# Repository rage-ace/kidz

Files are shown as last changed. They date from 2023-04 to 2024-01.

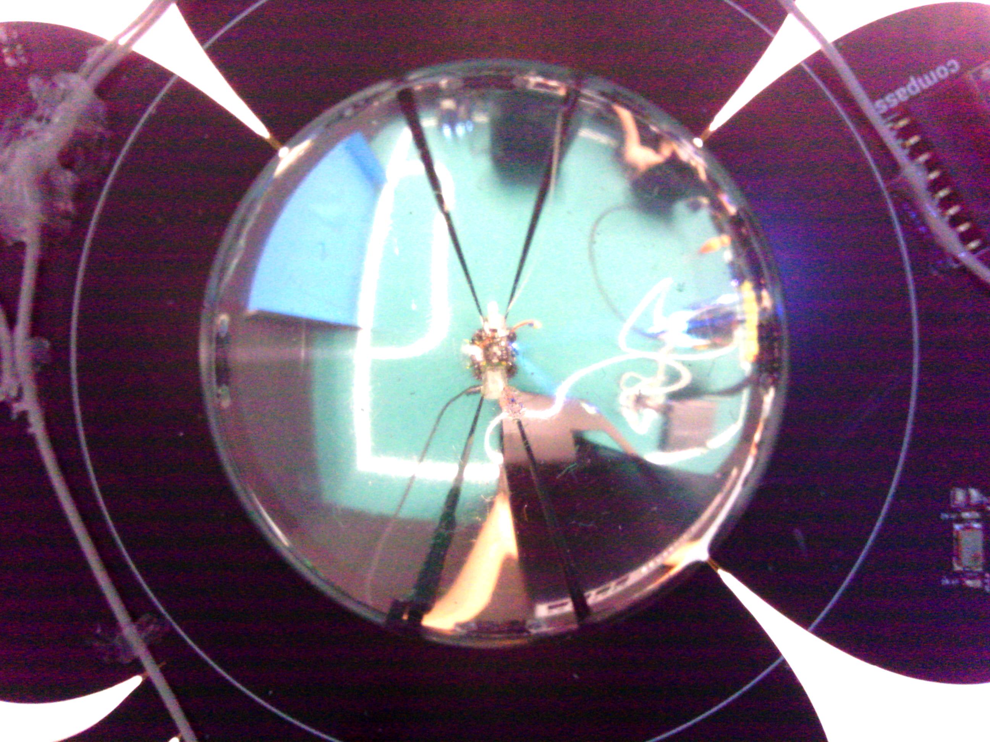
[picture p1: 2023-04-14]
software/coral/snaps/img0002.jpg

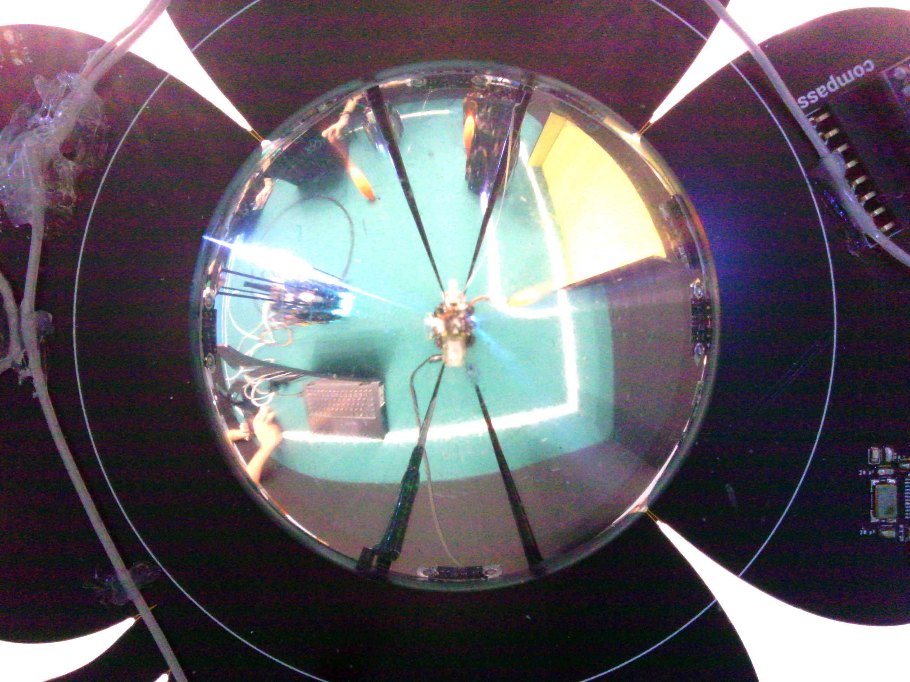
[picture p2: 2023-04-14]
software/coral/snaps/img0001.jpg

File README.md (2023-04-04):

# kidz

Find out more at [notes.skytect.one/robocup](https://notes.skytect.one/robocup)!

```bash
.
├── designs/               # All CAD designs are located here
│   └── pcb-schematics/        # PCB schematics
│       ├── layer1/                # Layer 1 PCB
│       ├── layer2/                # Layer 2 PCB
│       ├── layer3/                # Layer 3 PCB
│       └── layer4/                # Layer 4 PCB
├── software/              # All code is located here
│   ├── coral/             # Code for the Coral Dev Board Mini
│   │   └── ...
│   └── microcontrollers/  # Code for the Teensy 4.0 and STM32F103CBT6s
│       ├── include/           # Shared header files
│       ├── lib/               # Shared libraries
│       ├── src/
│       │   ├── stm32_mux/         # Code for the Layer 1 STM32
│       │   │   ├── include/           # Header files
│       │   │   ├── lib/               # Libraries
│       │   │   ├── main.cpp           # Source code
│       │   │   └── ...
│       │   ├── stm32_imu/         # Code for the Layer 4 IMU STM32
│       │   │   ├── include/           # Header files
│       │   │   ├── lib/               # Libraries
│       │   │   ├── main.cpp           # Source code
│       │   │   └── ...
│       │   ├── stm32_tof/        # Code for the Layer 4 TOF STM32
│       │   │   ├── include/           # Header files
│       │   │   ├── lib/               # Libraries
│       │   │   ├── main.cpp           # Source code
│       │   │   └── ...
│       │   ├── teensy/            # Code for the Layer 3 Teensy
│       │   │   ├── include/           # Header files
│       │   │   ├── lib/               # Libraries
│       │   │   ├── main.cpp           # Source code
│       │   │   └── ...
│       │   └── ...            # Shared source code
│       ├── platform.ini       # PlatformIO configuration file
│       └── ...
├── .gitignore
├── LICENSE
└── README.md
```

## Coral

[Click Me!](software/coral)

## Microcontrollers

### Execution

```bash
cd software/microcontrollers
# Upload and run to Teensy
pio run -e teensy -t upload -t monitor
# Upload to Layer 1 STM32
pio run -e stm32_mux -t upload
```

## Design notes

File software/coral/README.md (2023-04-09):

# Camera 📸

## Setup

```bash
 # Connect to a network to SSH over, and set hostname to "kidz.local"
sudo nmtui
sudo nano /etc/hosts  # Also change your hostname here to "kidz"

# Setup autofocus
snapshot  # Send 'r' to focus once
# The run scripts disable autofocus

# Install python dependencies
sudo python3 -m pip install -r requirements.txt  # We will be running the script with root

# Set up service
sudo apt install -y screen
sudo cp camera.service /etc/systemd/system/
sudo systemctl enable camera  # TODO: THIS DOES NOT WORK (https://stackoverflow.com/questions/75961521/pyserial-write-raises-errno-5-input-output-error-a-while-after-startup-when)
```

## Execution

```bash
# Run the version with a webserver debugger
# Access it at http://kidz.local:8080
sudo sh run_server.sh

# Run the headless version
sudo sh run_noserver.sh
```

## Development

```bash
# Install dependenceis
sudo apt install -y python3-dev
python3 -m pip install --user black pipreqs
echo 'export PATH="/home/mendel/.local/bin:$PATH"' >> ~/.bashrc

pipreqs . --force  # Capture python dependencies to requirements.txt
black .  # Reformat all code
```

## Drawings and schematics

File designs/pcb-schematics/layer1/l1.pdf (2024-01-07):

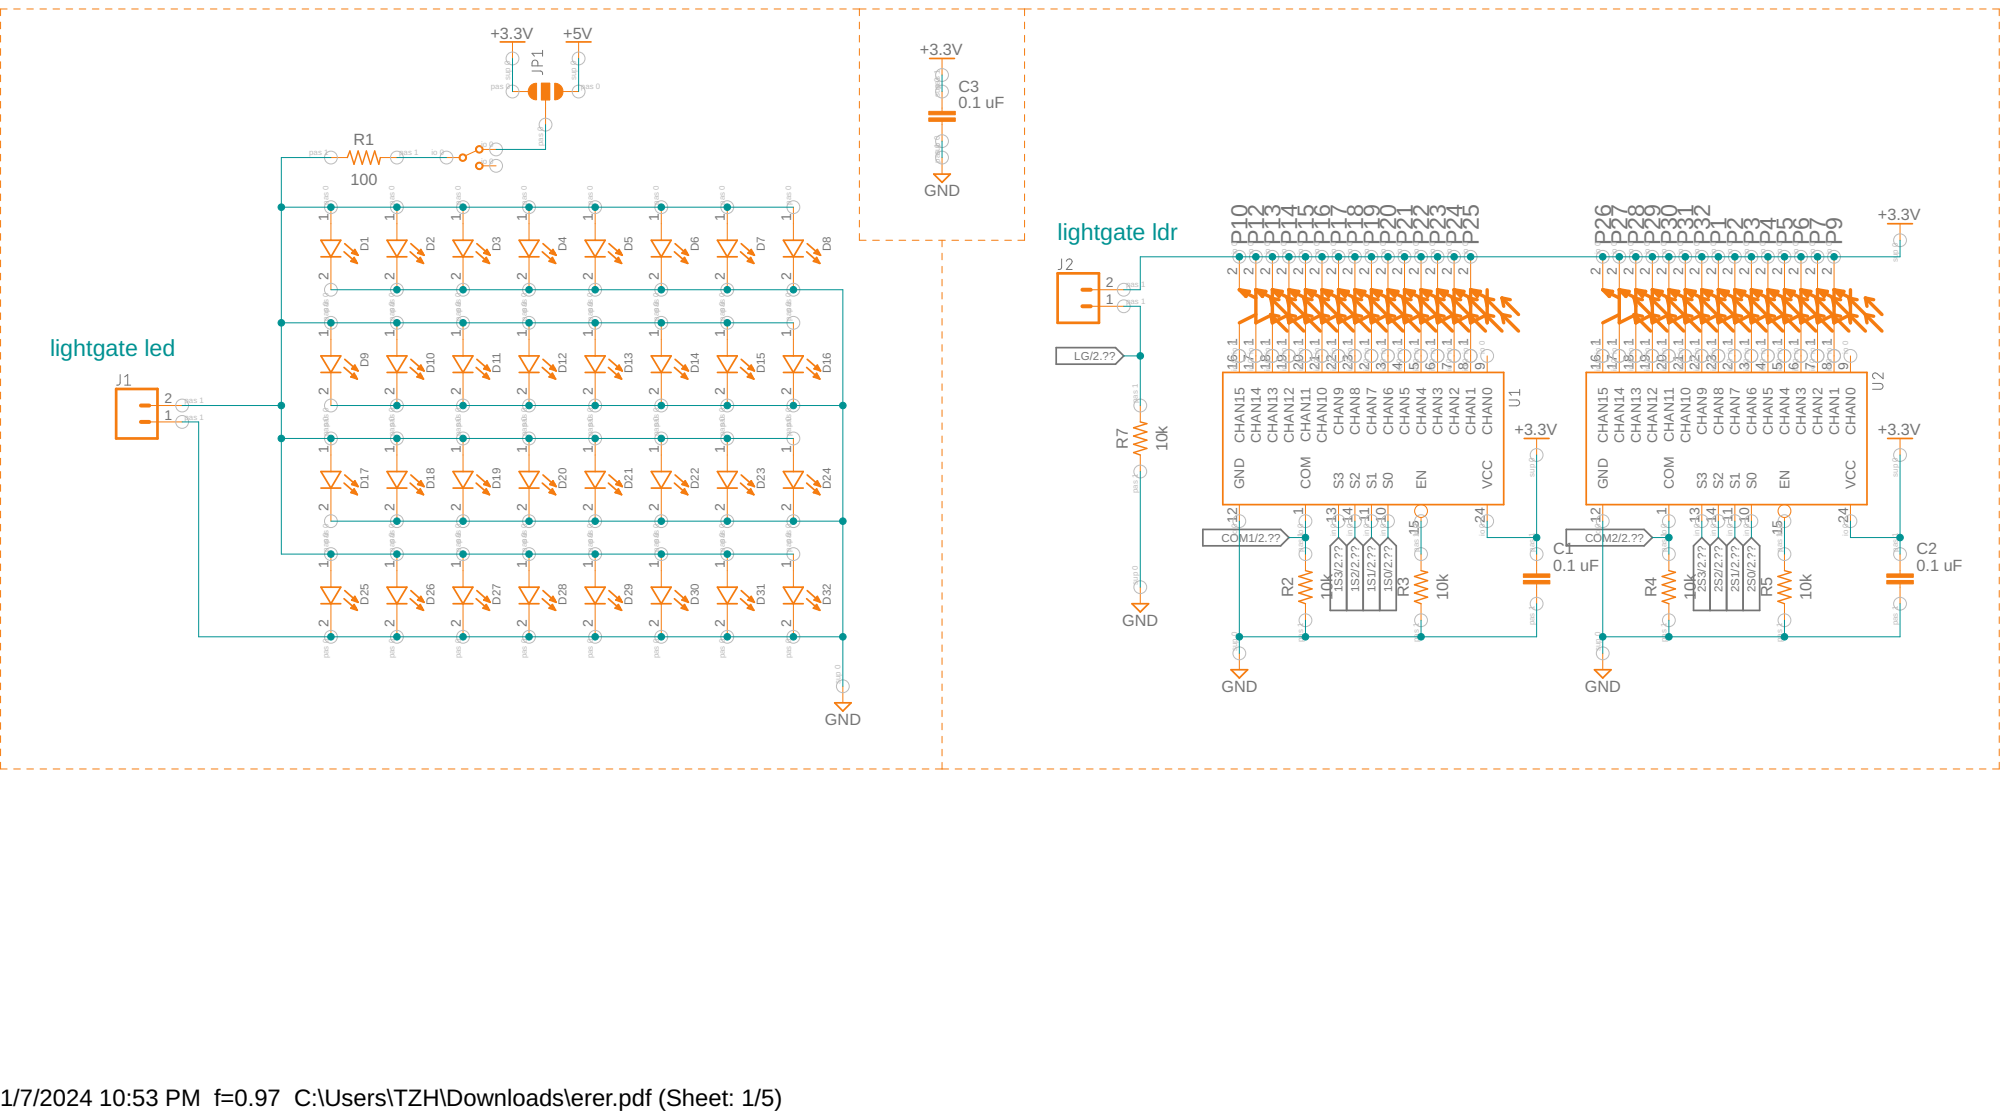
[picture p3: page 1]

1/7/2024 10:53 PM f=0.97 C:\Users\TZH\Downloads\erer.pdf (Sheet: 1/5)

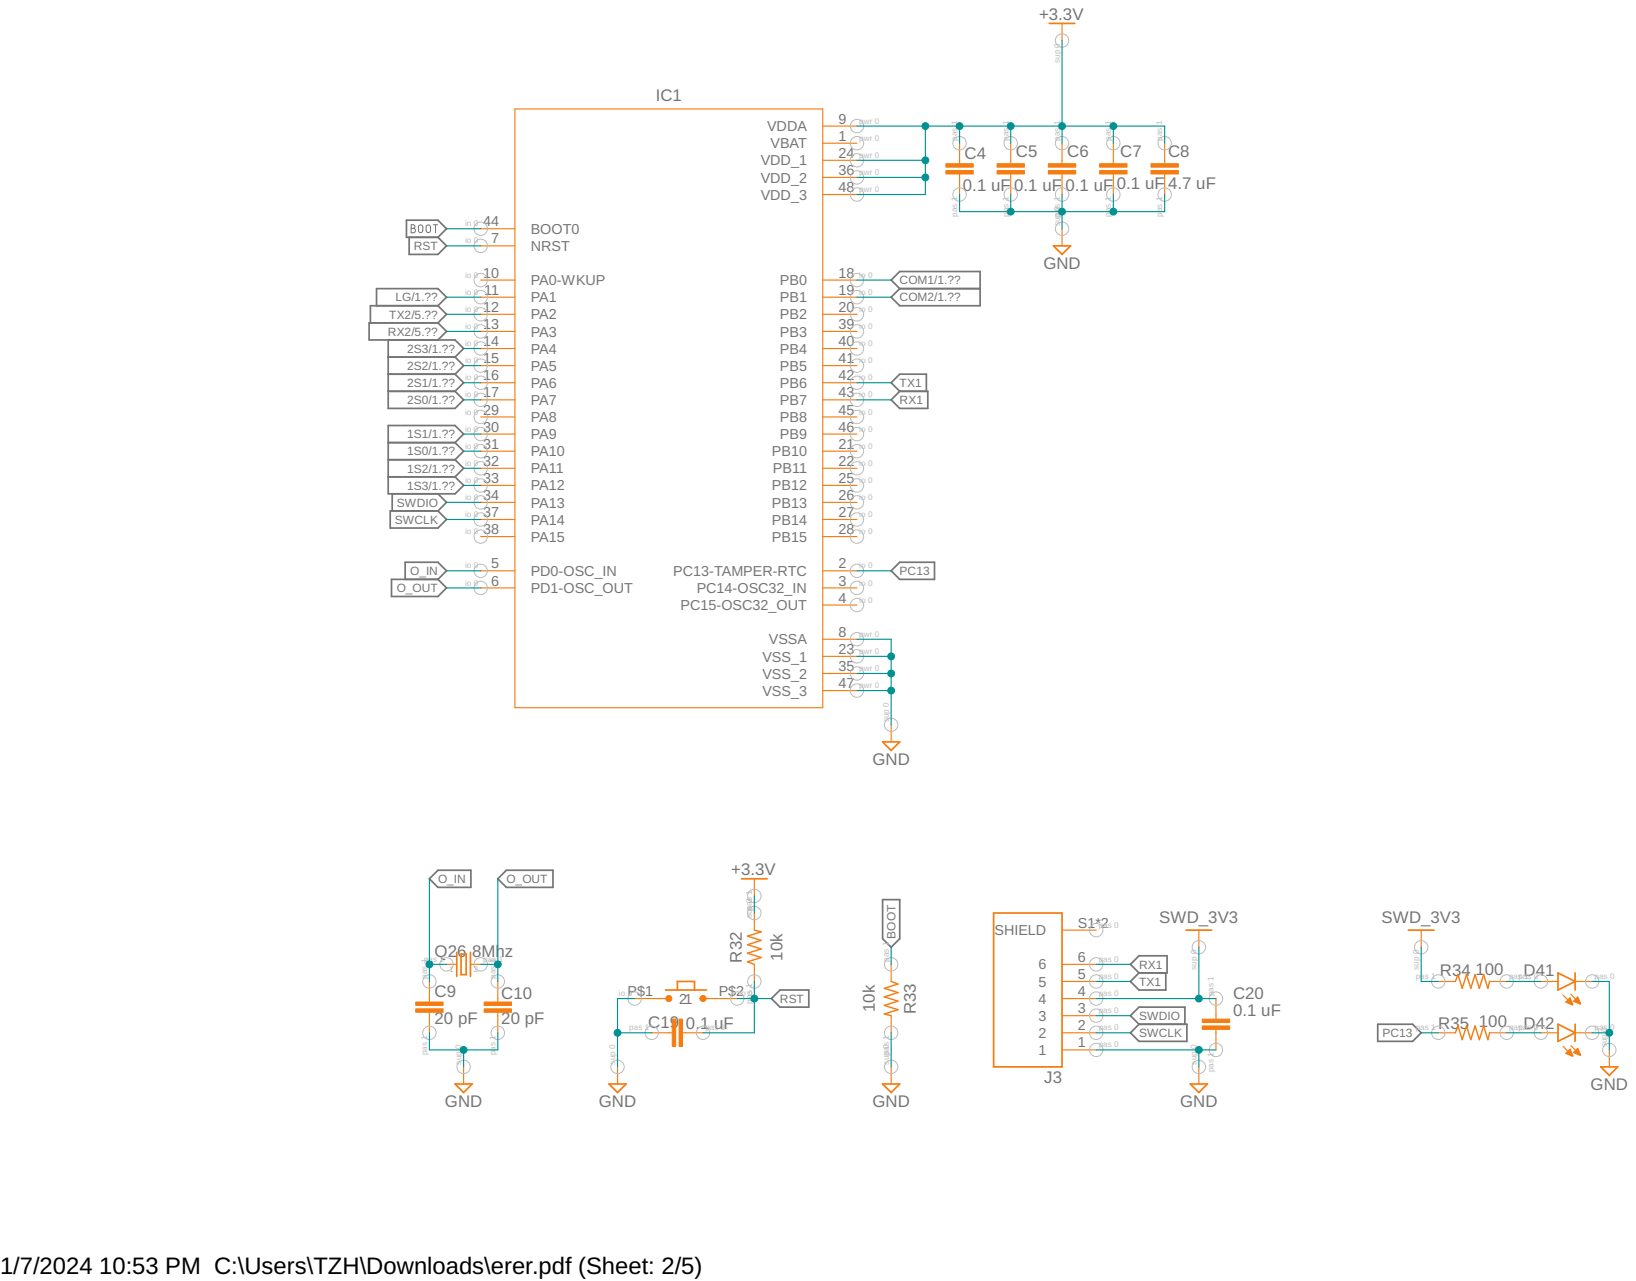
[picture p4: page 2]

1/7/2024 10:53 PM C:\Users\TZH\Downloads\erer.pdf (Sheet: 2/5)

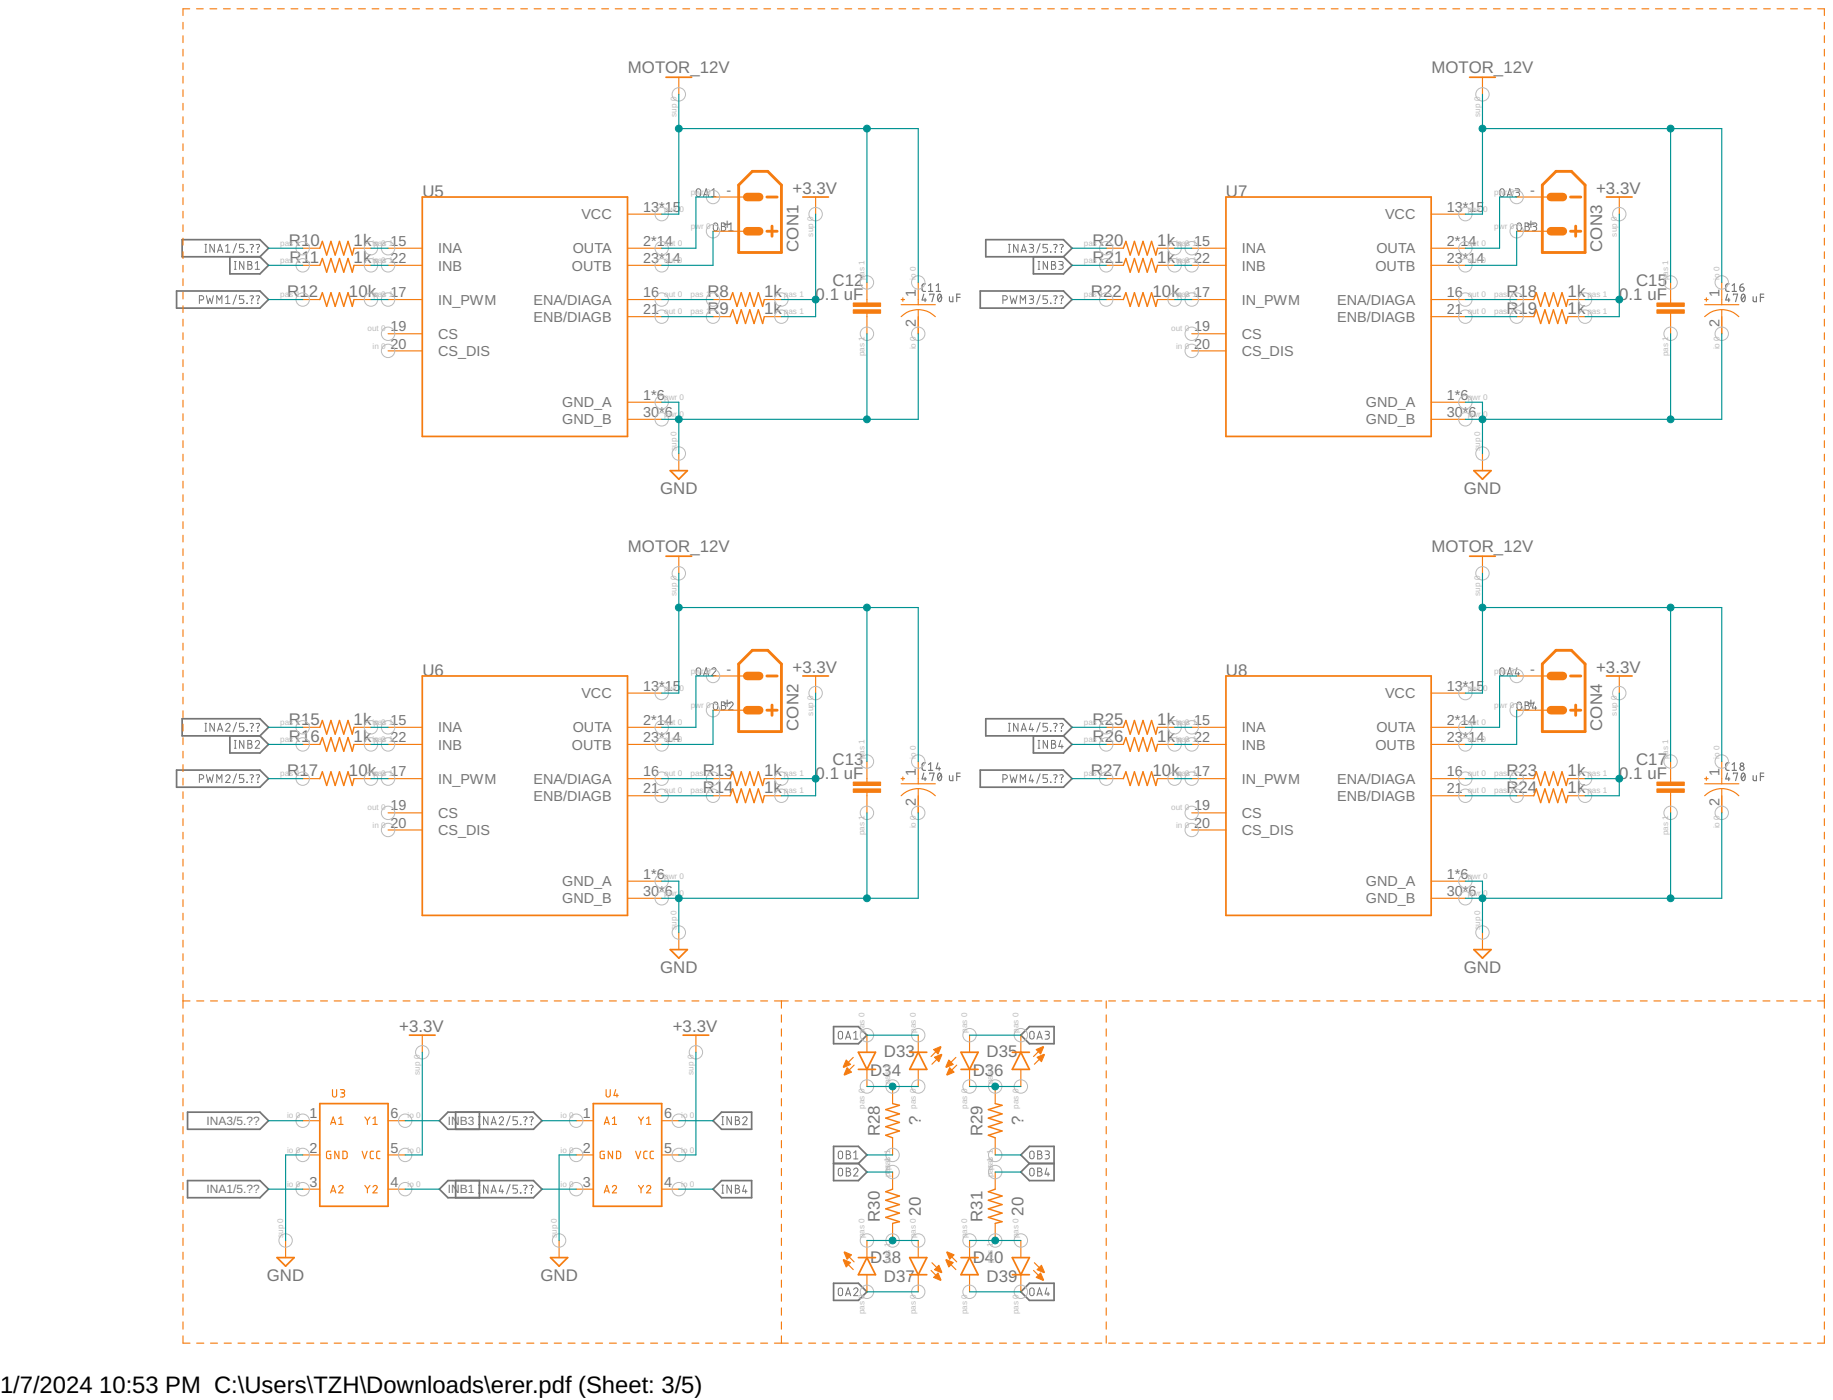
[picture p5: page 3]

1/7/2024 10:53 PM C:\Users\TZH\Downloads\erer.pdf (Sheet: 3/5)

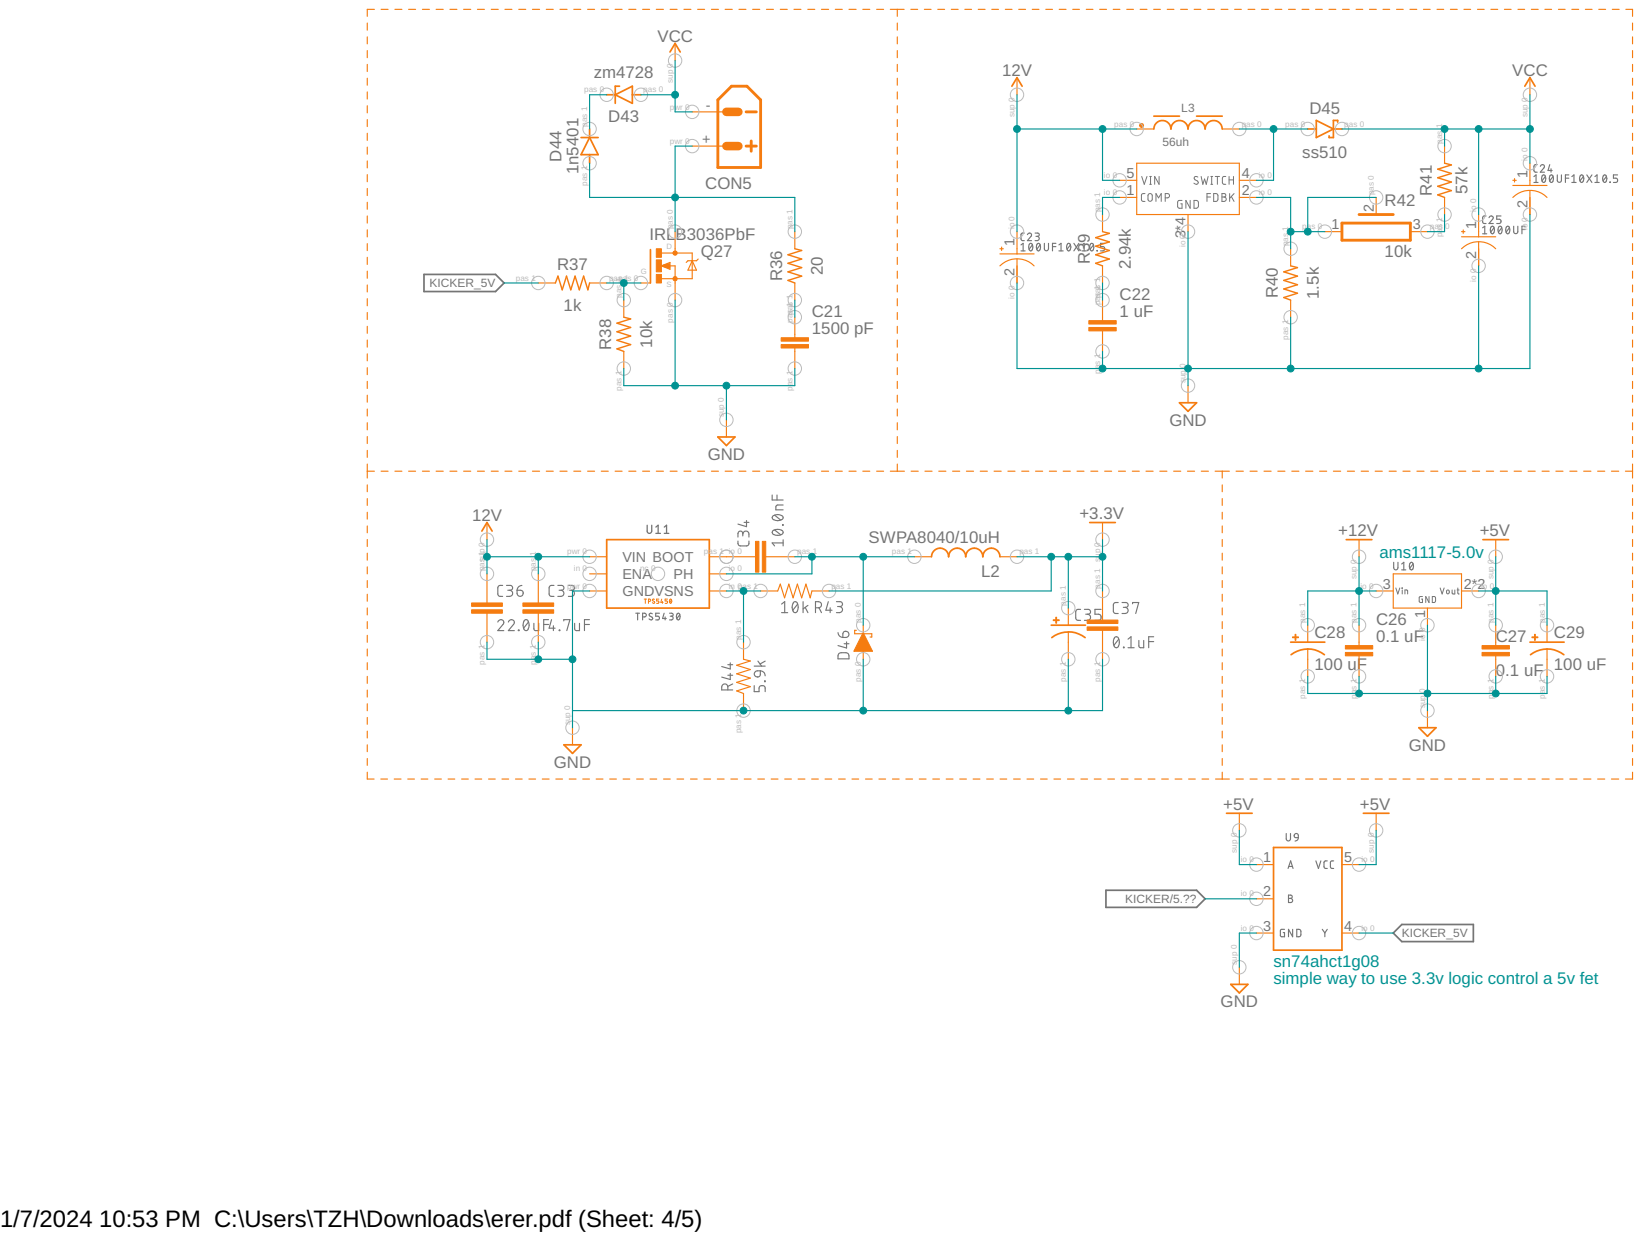
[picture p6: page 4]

pas 1 pas 1

sup 0
sn74ahct1g08
simple way to use 3.3v logic control a 5v fet

1/7/2024 10:53 PM C:\Users\TZH\Downloads\erer.pdf (Sheet: 4/5)

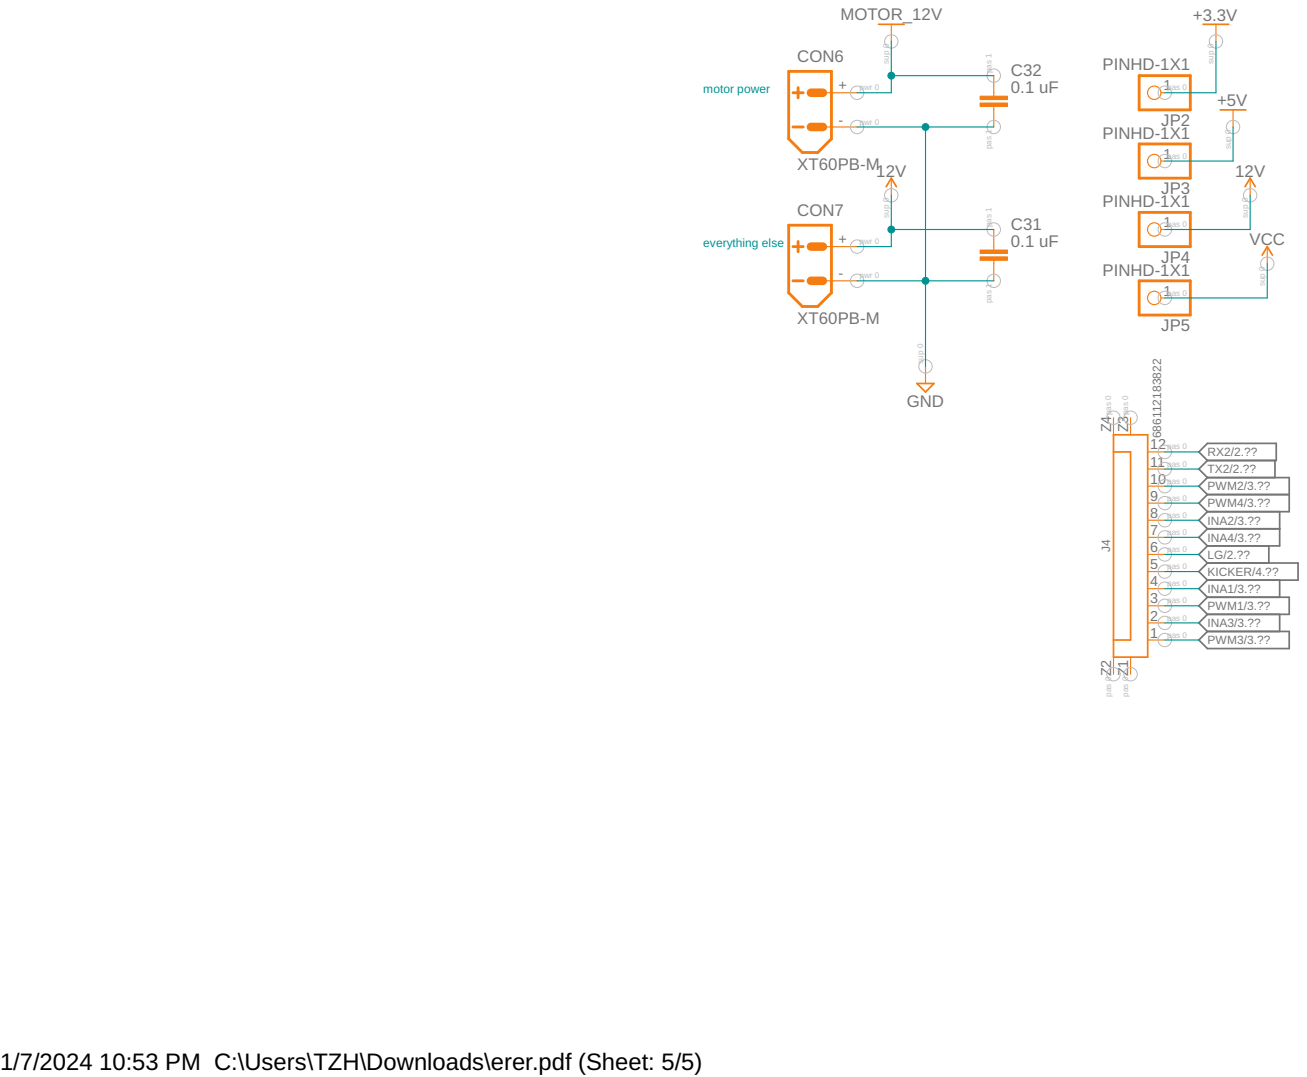
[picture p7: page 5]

1/7/2024 10:53 PM C:\Users\TZH\Downloads\erer.pdf (Sheet: 5/5)

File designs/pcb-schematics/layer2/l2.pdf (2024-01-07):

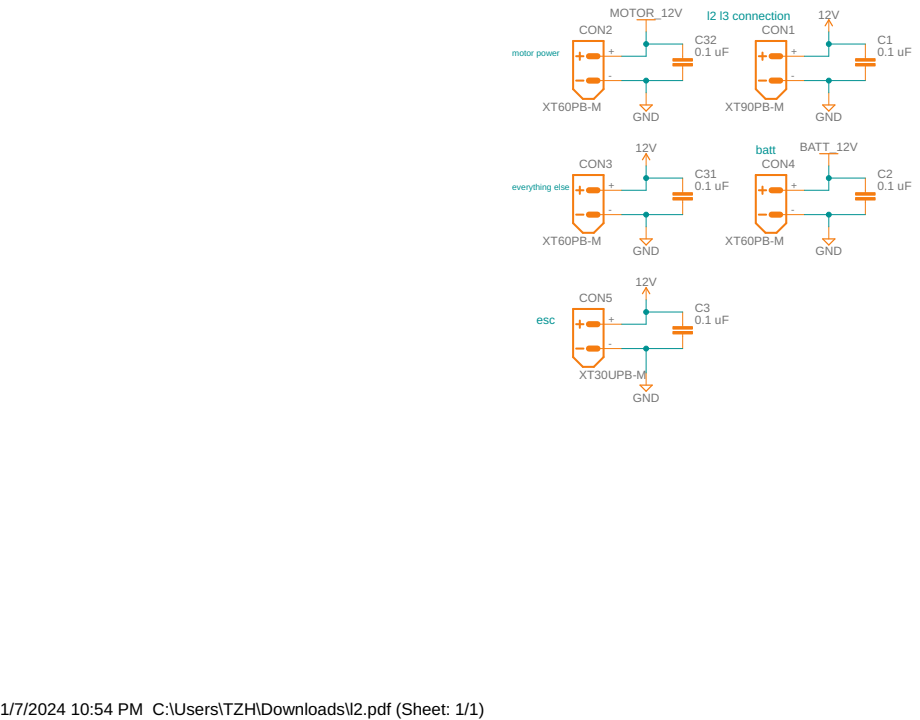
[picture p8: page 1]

1/7/2024 10:54 PM C:\Users\TZH\Downloads\l2.pdf (Sheet: 1/1)

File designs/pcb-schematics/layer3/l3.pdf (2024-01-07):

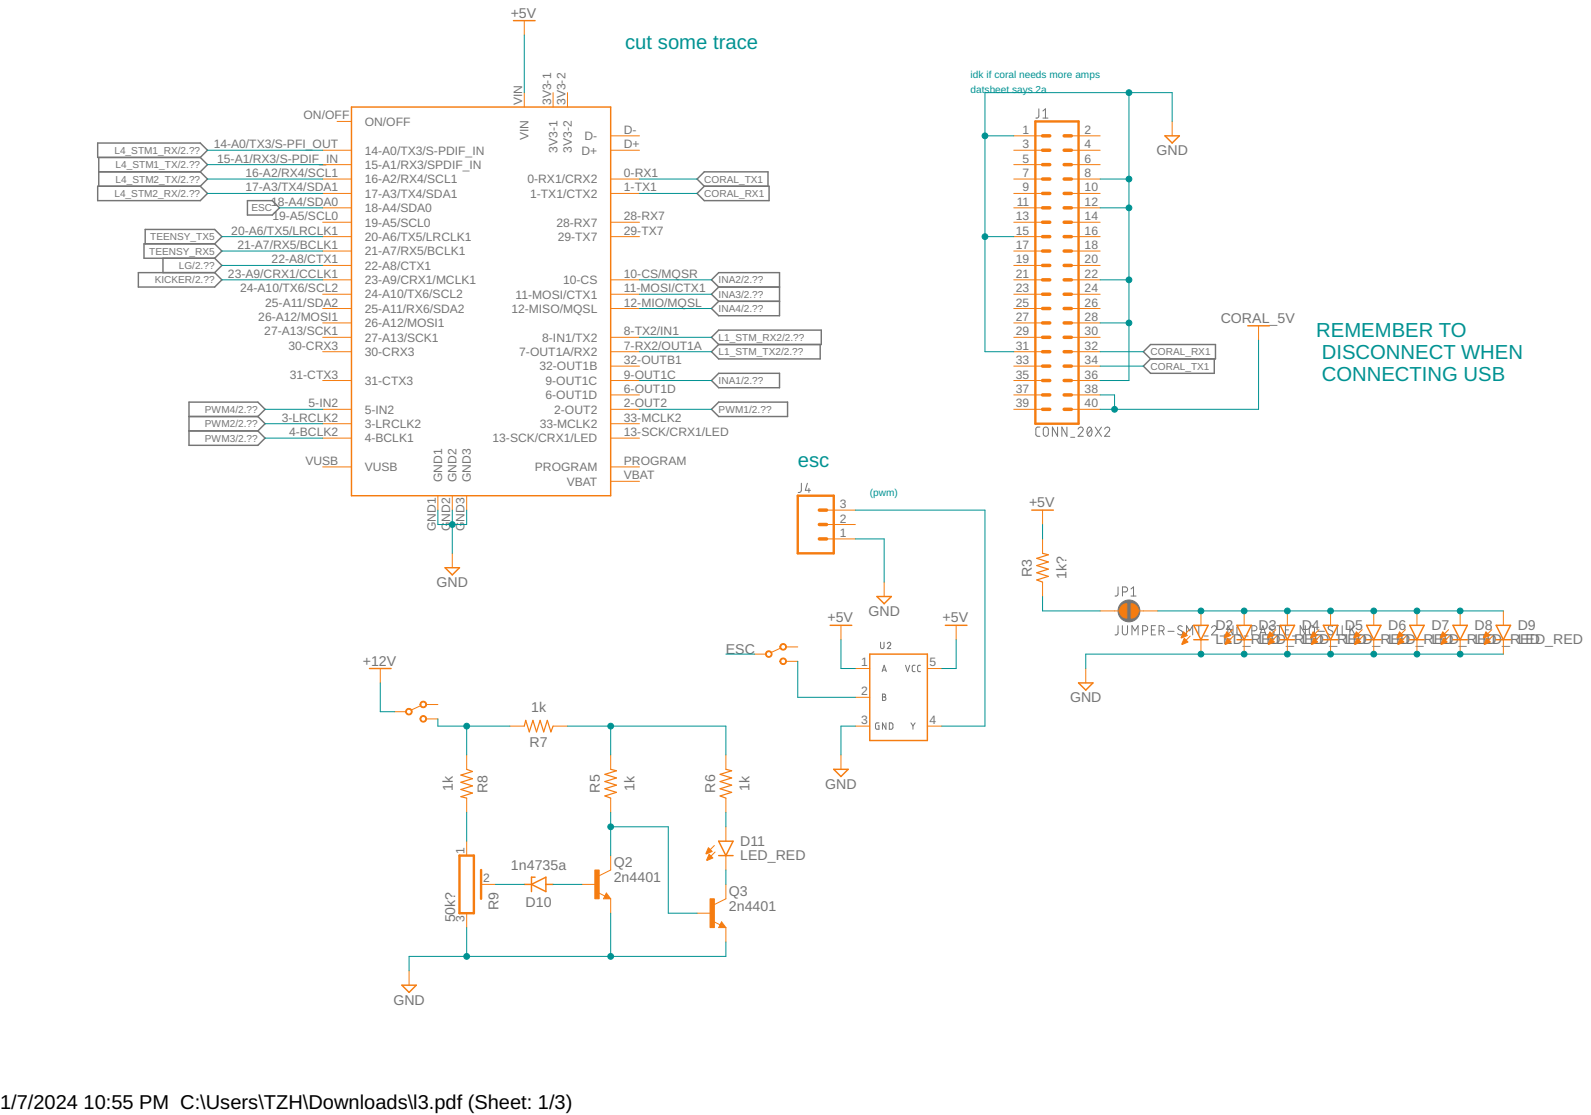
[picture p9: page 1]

idk if coral needs more amps datsheet says 2a

ON/OFF

1/7/2024 10:55 PM C:\Users\TZH\Downloads\l3.pdf (Sheet: 1/3)

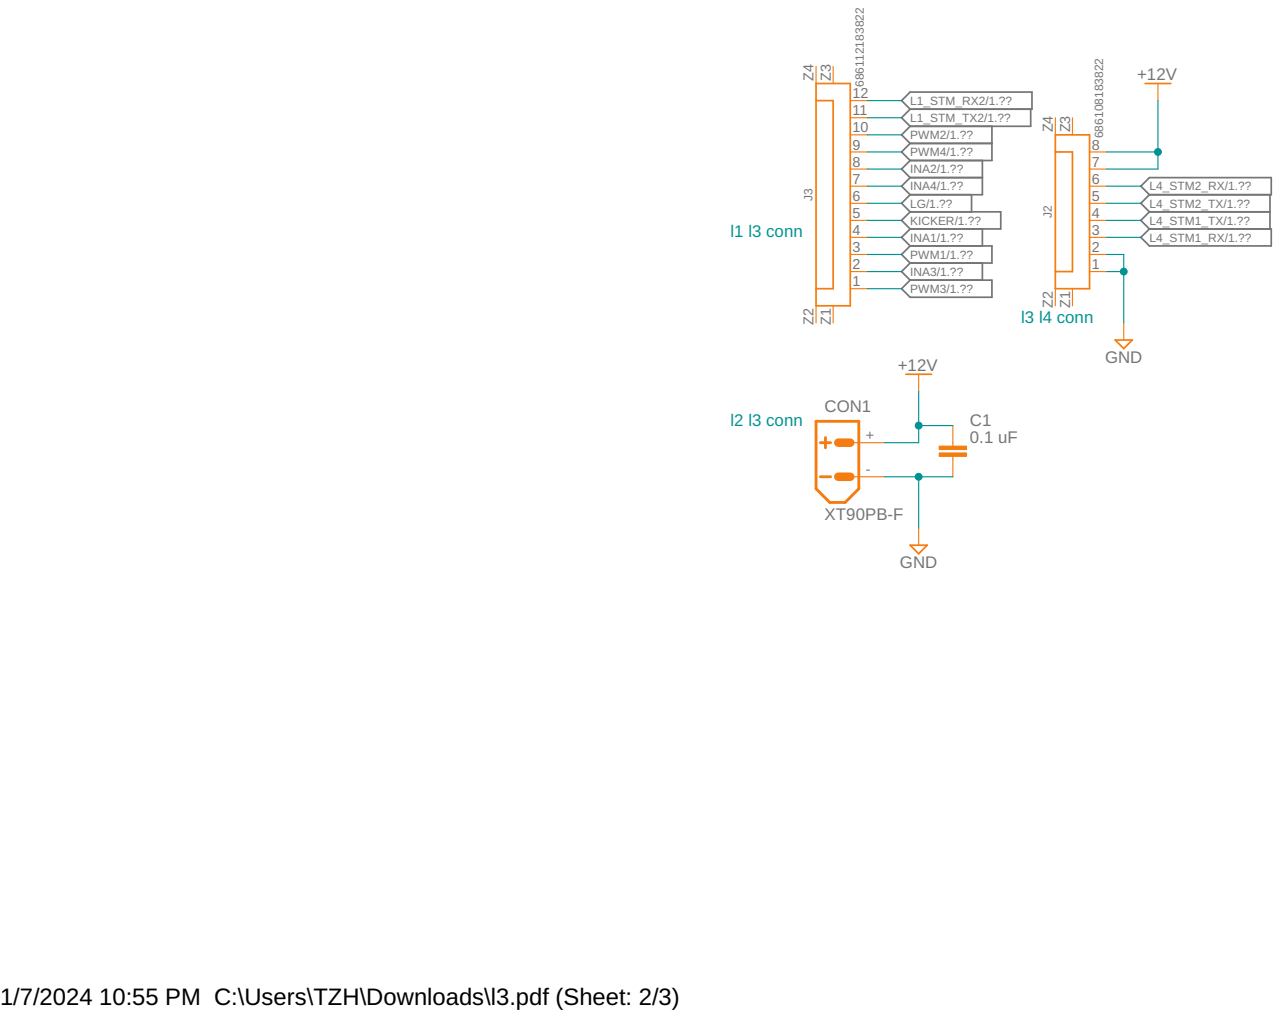
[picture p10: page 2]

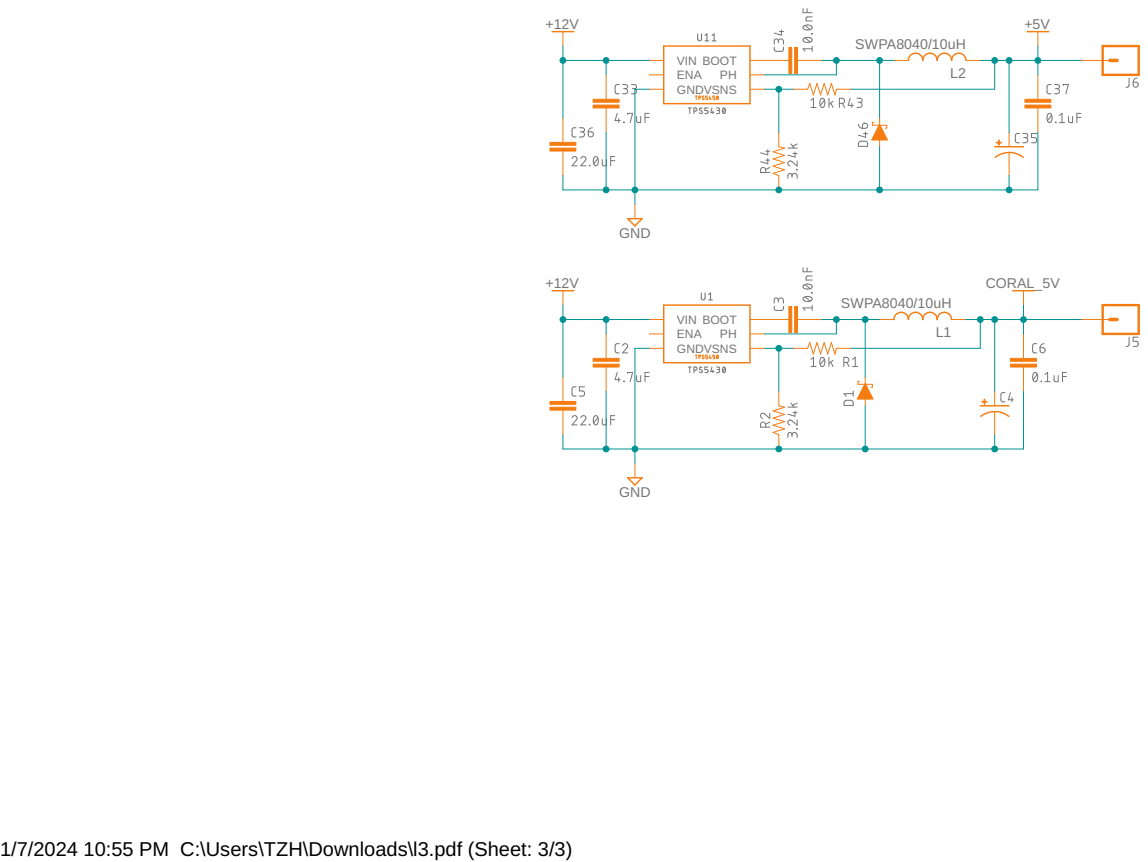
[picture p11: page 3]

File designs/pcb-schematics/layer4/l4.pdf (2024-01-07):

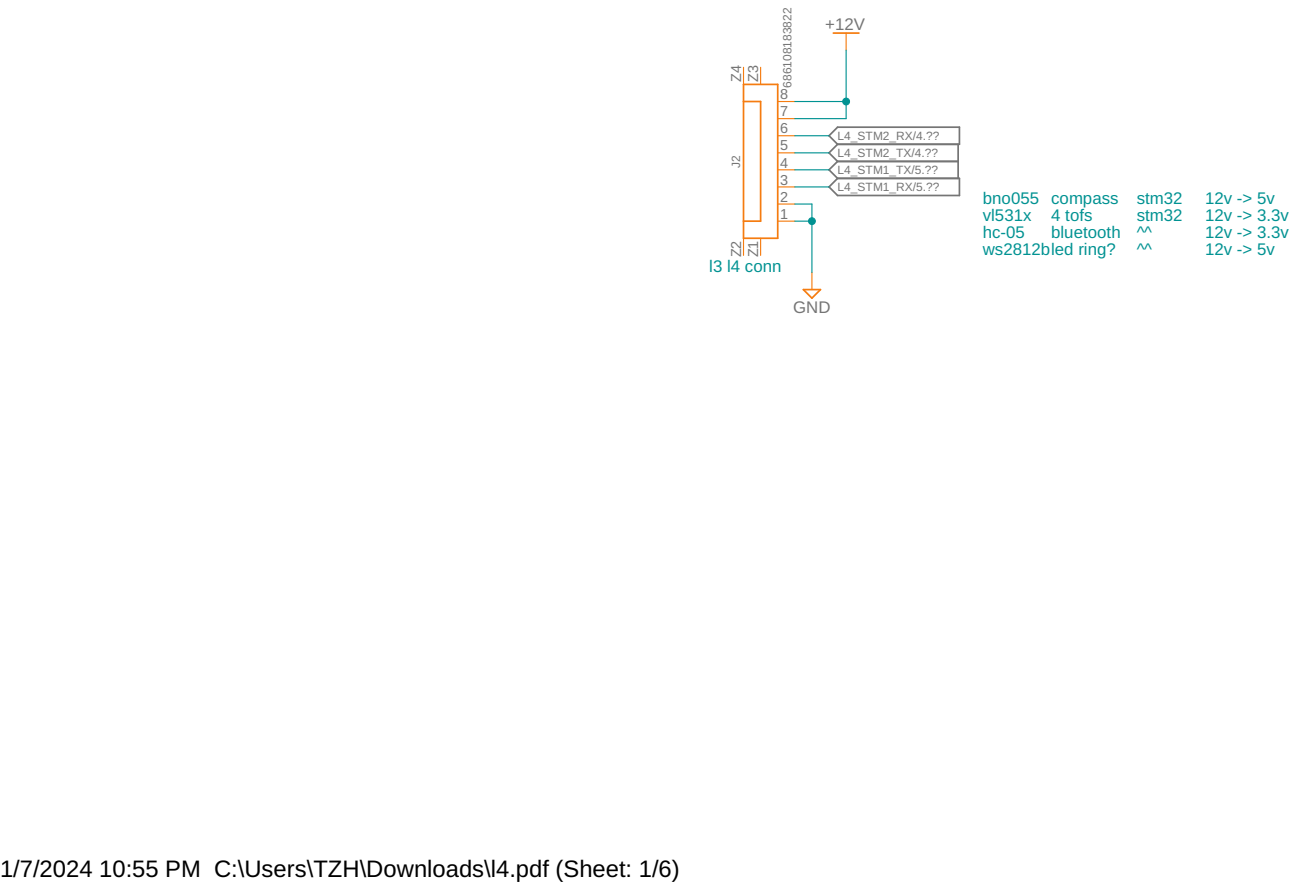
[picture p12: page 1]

1/7/2024 10:55 PM C:\Users\TZH\Downloads\l4.pdf (Sheet: 1/6)

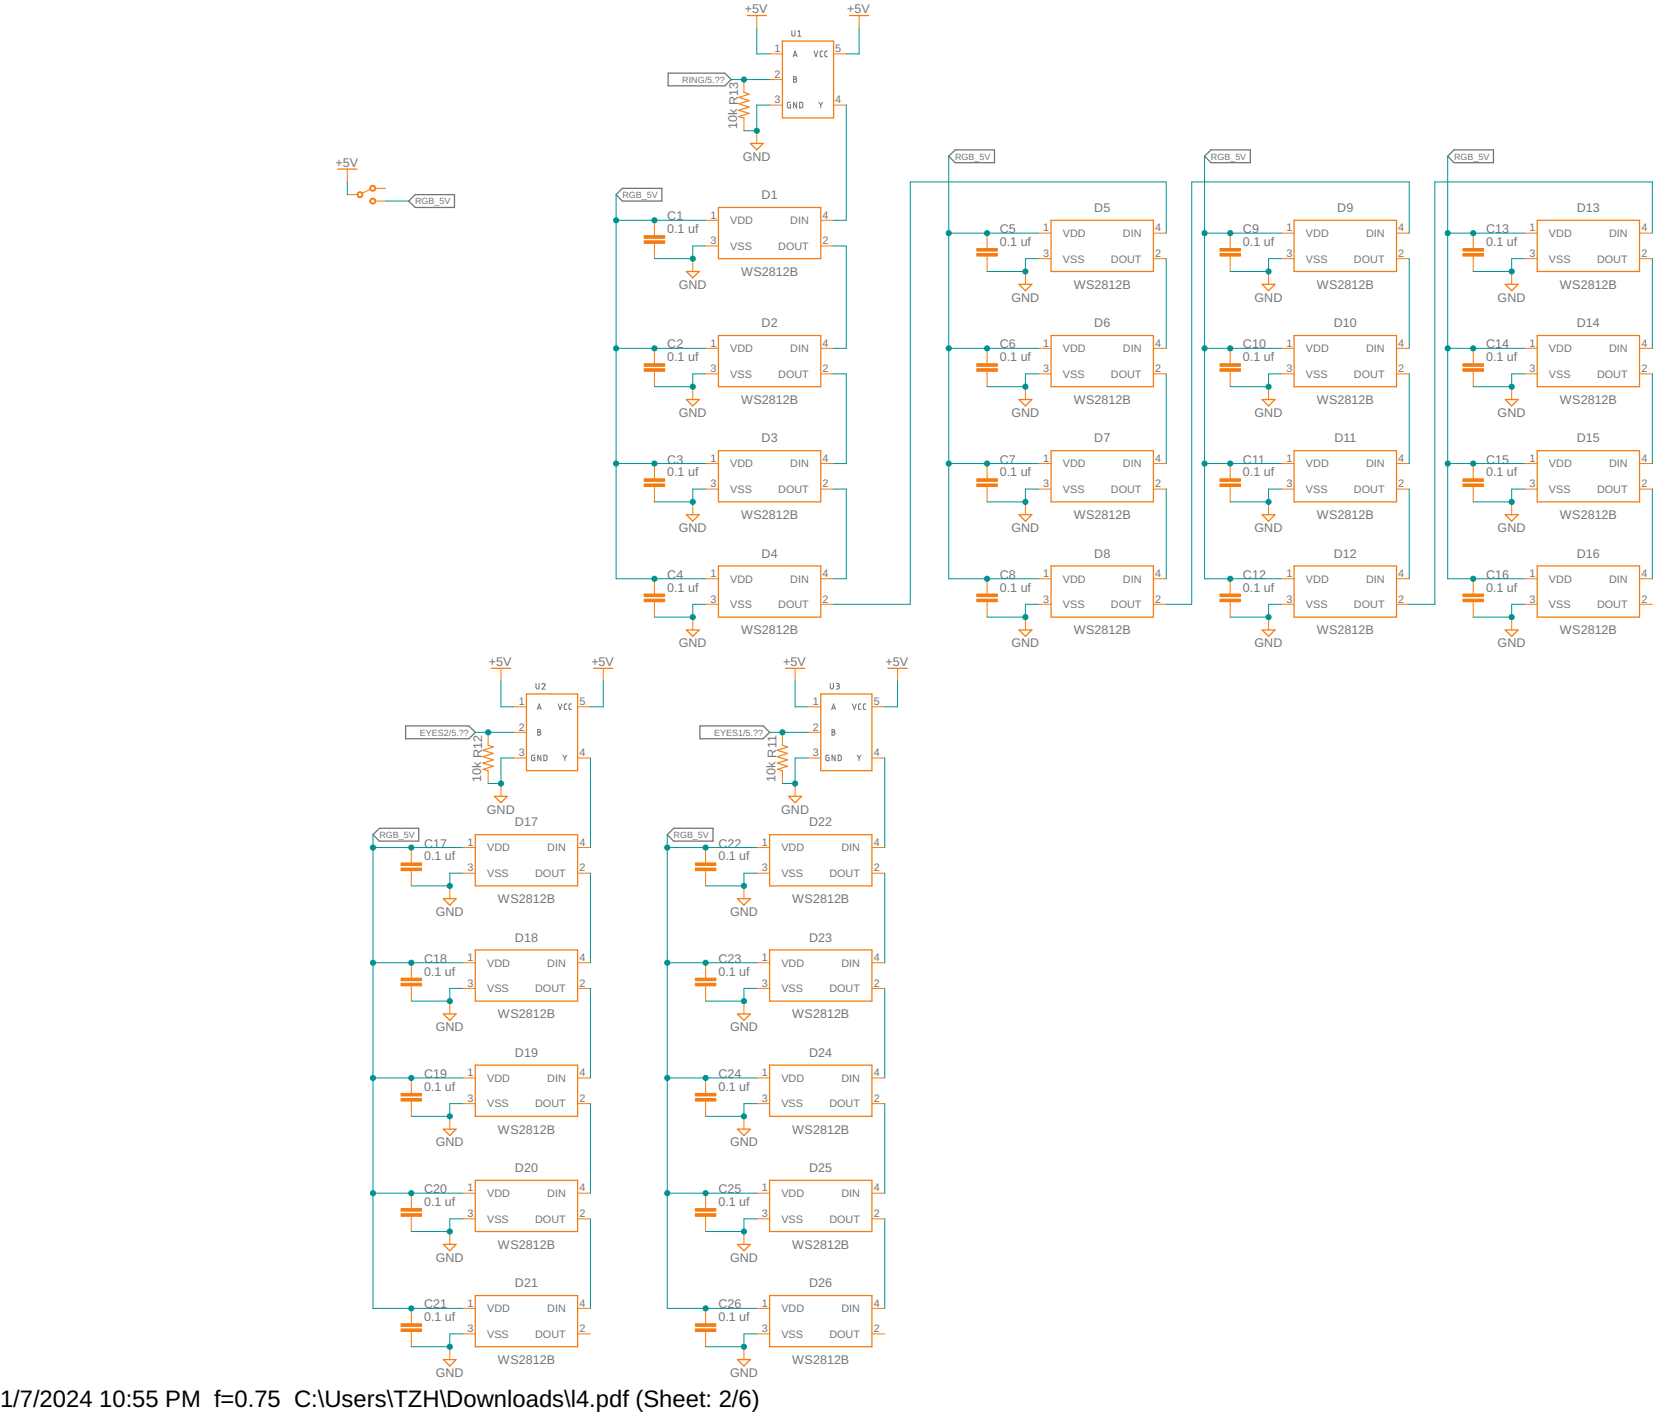
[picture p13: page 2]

1/7/2024 10:55 PM f=0.75 C:\Users\TZH\Downloads\l4.pdf (Sheet: 2/6)

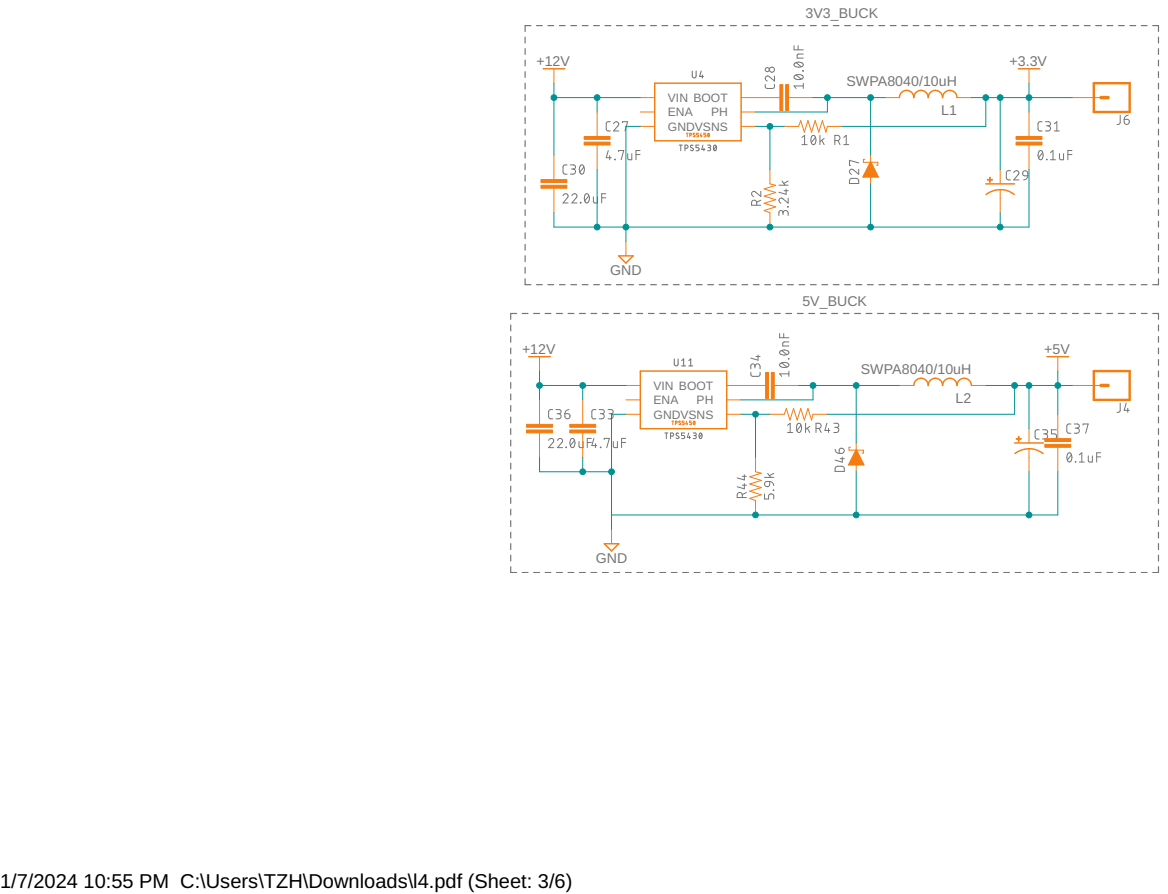
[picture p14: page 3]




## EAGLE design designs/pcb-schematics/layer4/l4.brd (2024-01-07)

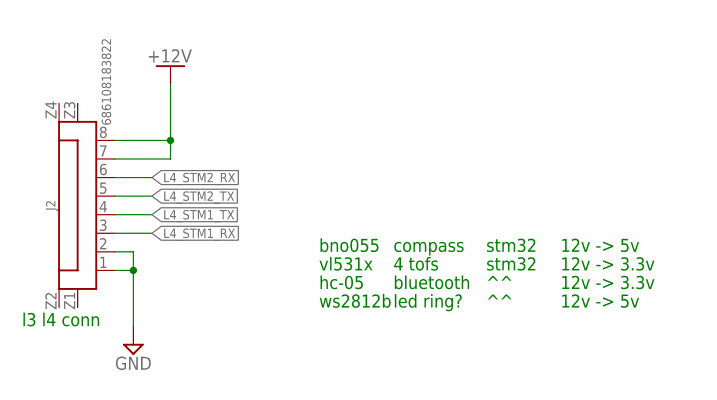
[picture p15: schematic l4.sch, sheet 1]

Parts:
J2: 686108183822

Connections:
+12V: J2.7, J2.8; also elsewhere on the board
GND: J2.1, J2.2; also elsewhere on the board
L4_STM1_RX: J2.3; also elsewhere on the board
L4_STM1_TX: J2.4; also elsewhere on the board
L4_STM2_RX: J2.6; also elsewhere on the board
L4_STM2_TX: J2.5; also elsewhere on the board

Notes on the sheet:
compass
stm32
4 tofs
bluetooth
led ring?
bno055
ws2812b
vl531x
hc-05
12v -> 5v
12v -> 3.3v
l3 l4 conn

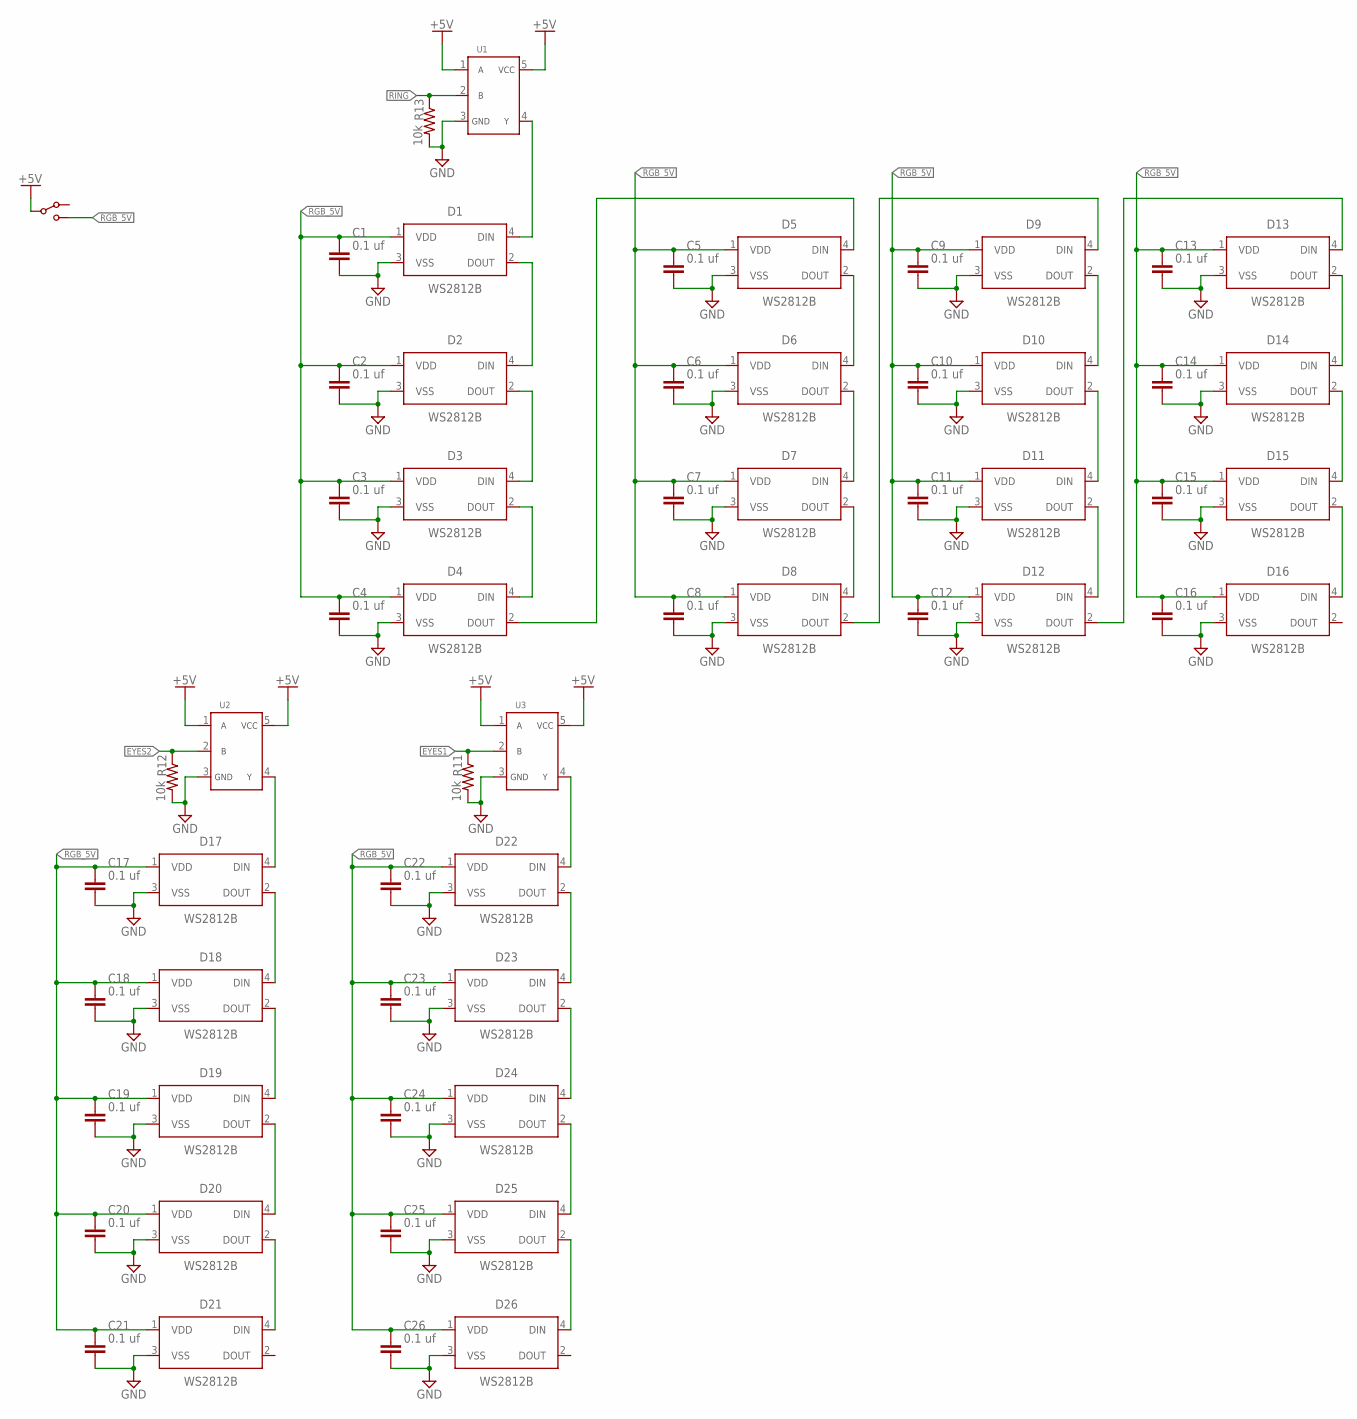
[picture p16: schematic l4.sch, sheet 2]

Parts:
C1, C2, C3, C4, C5, C6, C7, C8, C9, C10, C11, C12, C13, C14, C15, C16, C17, C18, C19, C20, C21, C22, C23, C24, C25, C26: 0.1 uf; CAPC1608X85
D1, D2, D3, D4, D5, D6, D7, D8, D9, D10, D11, D12, D13, D14, D15, D16, D17, D18, D19, D20, D21, D22, D23, D24, D25, D26: WS2812B
R11, R12, R13: 10k; RESC1608X60
S1: SPDT-SLIDE-SWITCHSWITCH-TH; SWITCH-TH
U1, U2, U3: SN74AHCT1G08; SOT23-5

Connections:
+5V: S1.P$2, U1.1, U1.5, U2.1, U2.5, U3.1, U3.5; also elsewhere on the board
EYES1: R11.1, U3.2; also elsewhere on the board
EYES2: R12.1, U2.2; also elsewhere on the board
GND: C1.2, C2.2, C3.2, C4.2, C5.2, C6.2, C7.2, C8.2, C9.2, C10.2, C11.2, C12.2, C13.2, C14.2, C15.2, C16.2, C17.2, C18.2, C19.2, C20.2, C21.2, C22.2, C23.2, C24.2, C25.2, C26.2, D1.3 (VSS), D2.3 (VSS), D3.3 (VSS), D4.3 (VSS), D5.3 (VSS), D6.3 (VSS), D7.3 (VSS), D8.3 (VSS), D9.3 (VSS), D10.3 (VSS), D11.3 (VSS), D12.3 (VSS), D13.3 (VSS), D14.3 (VSS), D15.3 (VSS), D16.3 (VSS), D17.3 (VSS), D18.3 (VSS), D19.3 (VSS), D20.3 (VSS), D21.3 (VSS), D22.3 (VSS), D23.3 (VSS), D24.3 (VSS), D25.3 (VSS), D26.3 (VSS), R11.2, R12.2, R13.2, U1.3, U2.3, U3.3; also elsewhere on the board
unnamed: D1.2 (DOUT), D2.4 (DIN)
unnamed: D2.2 (DOUT), D3.4 (DIN)
unnamed: D3.2 (DOUT), D4.4 (DIN)
unnamed: D9.2 (DOUT), D10.4 (DIN)
unnamed: D10.2 (DOUT), D11.4 (DIN)
unnamed: D1.4 (DIN), U1.4
unnamed: D11.2 (DOUT), D12.4 (DIN)
unnamed: D15.2 (DOUT), D16.4 (DIN)
unnamed: D14.2 (DOUT), D15.4 (DIN)
unnamed: D13.2 (DOUT), D14.4 (DIN)
unnamed: D5.2 (DOUT), D6.4 (DIN)
unnamed: D6.2 (DOUT), D7.4 (DIN)
unnamed: D7.2 (DOUT), D8.4 (DIN)
unnamed: D8.2 (DOUT), D9.4 (DIN)
unnamed: D12.2 (DOUT), D13.4 (DIN)
unnamed: D4.2 (DOUT), D5.4 (DIN)
unnamed: D20.2 (DOUT), D21.4 (DIN)
unnamed: D19.2 (DOUT), D20.4 (DIN)
unnamed: D18.2 (DOUT), D19.4 (DIN)
unnamed: D17.2 (DOUT), D18.4 (DIN)
unnamed: D22.2 (DOUT), D23.4 (DIN)
unnamed: D23.2 (DOUT), D24.4 (DIN)
unnamed: D24.2 (DOUT), D25.4 (DIN)
unnamed: D25.2 (DOUT), D26.4 (DIN)
unnamed: D22.4 (DIN), U3.4
unnamed: D17.4 (DIN), U2.4
RGB_5V: C1.1, C2.1, C3.1, C4.1, C5.1, C6.1, C7.1, C8.1, C9.1, C10.1, C11.1, C12.1, C13.1, C14.1, C15.1, C16.1, C17.1, C18.1, C19.1, C20.1, C21.1, C22.1, C23.1, C24.1, C25.1, C26.1, D1.1 (VDD), D2.1 (VDD), D3.1 (VDD), D4.1 (VDD), D5.1 (VDD), D6.1 (VDD), D7.1 (VDD), D8.1 (VDD), D9.1 (VDD), D10.1 (VDD), D11.1 (VDD), D12.1 (VDD), D13.1 (VDD), D14.1 (VDD), D15.1 (VDD), D16.1 (VDD), D17.1 (VDD), D18.1 (VDD), D19.1 (VDD), D20.1 (VDD), D21.1 (VDD), D22.1 (VDD), D23.1 (VDD), D24.1 (VDD), D25.1 (VDD), D26.1 (VDD), S1.P$3
RING: R13.1, U1.2; also elsewhere on the board

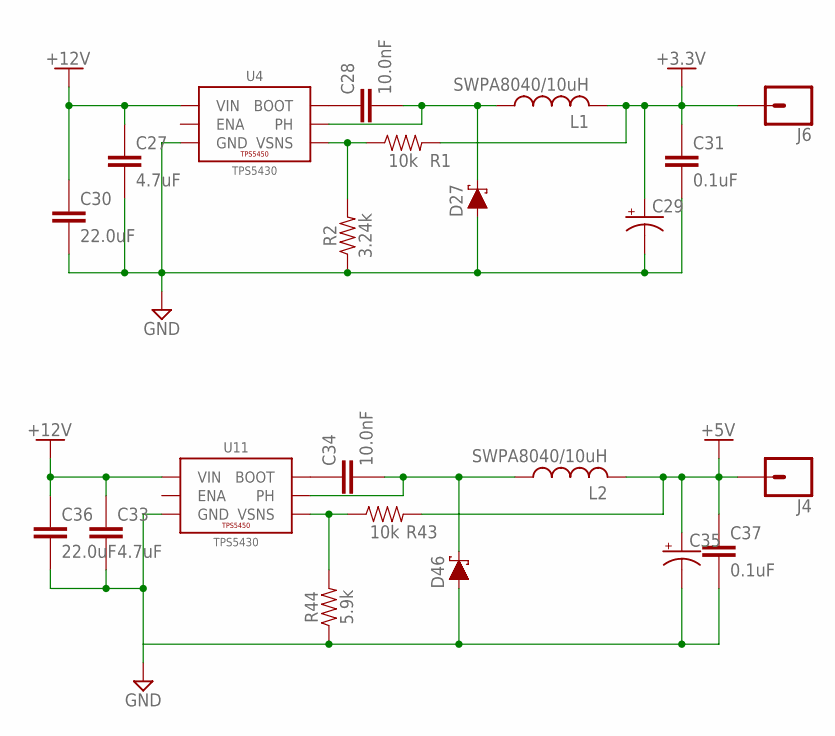
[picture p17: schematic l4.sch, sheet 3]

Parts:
C27, C33: 4.7uF; C0603
C28, C34: 10.0nF; C0603
C29, C35: 220uF; D/7343-31R
C30, C36: 22.0uF; C1210
C31, C37: 0.1uF; C0603
D27, D46: 3A/40V/500mV; SMA-DIODE
J4, J6: CONN_01; 1X01
L1, L2: SWPA8040/10uH; SWPA8040
R1, R43: 10k; R0603
R2: 3.24k; R0603
R44: 5.9k; R0603
U4, U11: TPS5430; POWERPAD-SOIC-8

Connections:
+3.3V: C29.+, C31.1, J6.1, L1.P2 (2), R1.2; also elsewhere on the board
+5V: C35.+, C37.1, J4.1, L2.P2 (2), R43.2; also elsewhere on the board
+12V: C27.1, C30.1, C33.1, C36.1, U4.7 (VIN), U11.7 (VIN); also elsewhere on the board
GND: C27.2, C29.-, C30.2, C31.2, C33.2, C35.-, C36.2, C37.2, D27.A, D46.A, R2.1, R44.1, U4.6 (GND), U4.9 (GND), U4.P$1 (GND), U4.P$2 (GND), U4.P$3 (GND), U4.P$4 (GND), U4.P$5 (GND), U4.P$6 (GND), U11.6 (GND), U11.9 (GND), U11.P$1 (GND), U11.P$2 (GND), U11.P$3 (GND), U11.P$4 (GND), U11.P$5 (GND), U11.P$6 (GND); also elsewhere on the board
unnamed: C28.2, D27.C, L1.P1 (1), U4.8 (PH)
unnamed: R1.1, R2.2, U4.4 (VSNS)
unnamed: C28.1, U4.1 (BOOT)
unnamed: C34.2, D46.C, L2.P1 (1), U11.8 (PH)
unnamed: R43.1, R44.2, U11.4 (VSNS)
unnamed: C34.1, U11.1 (BOOT)

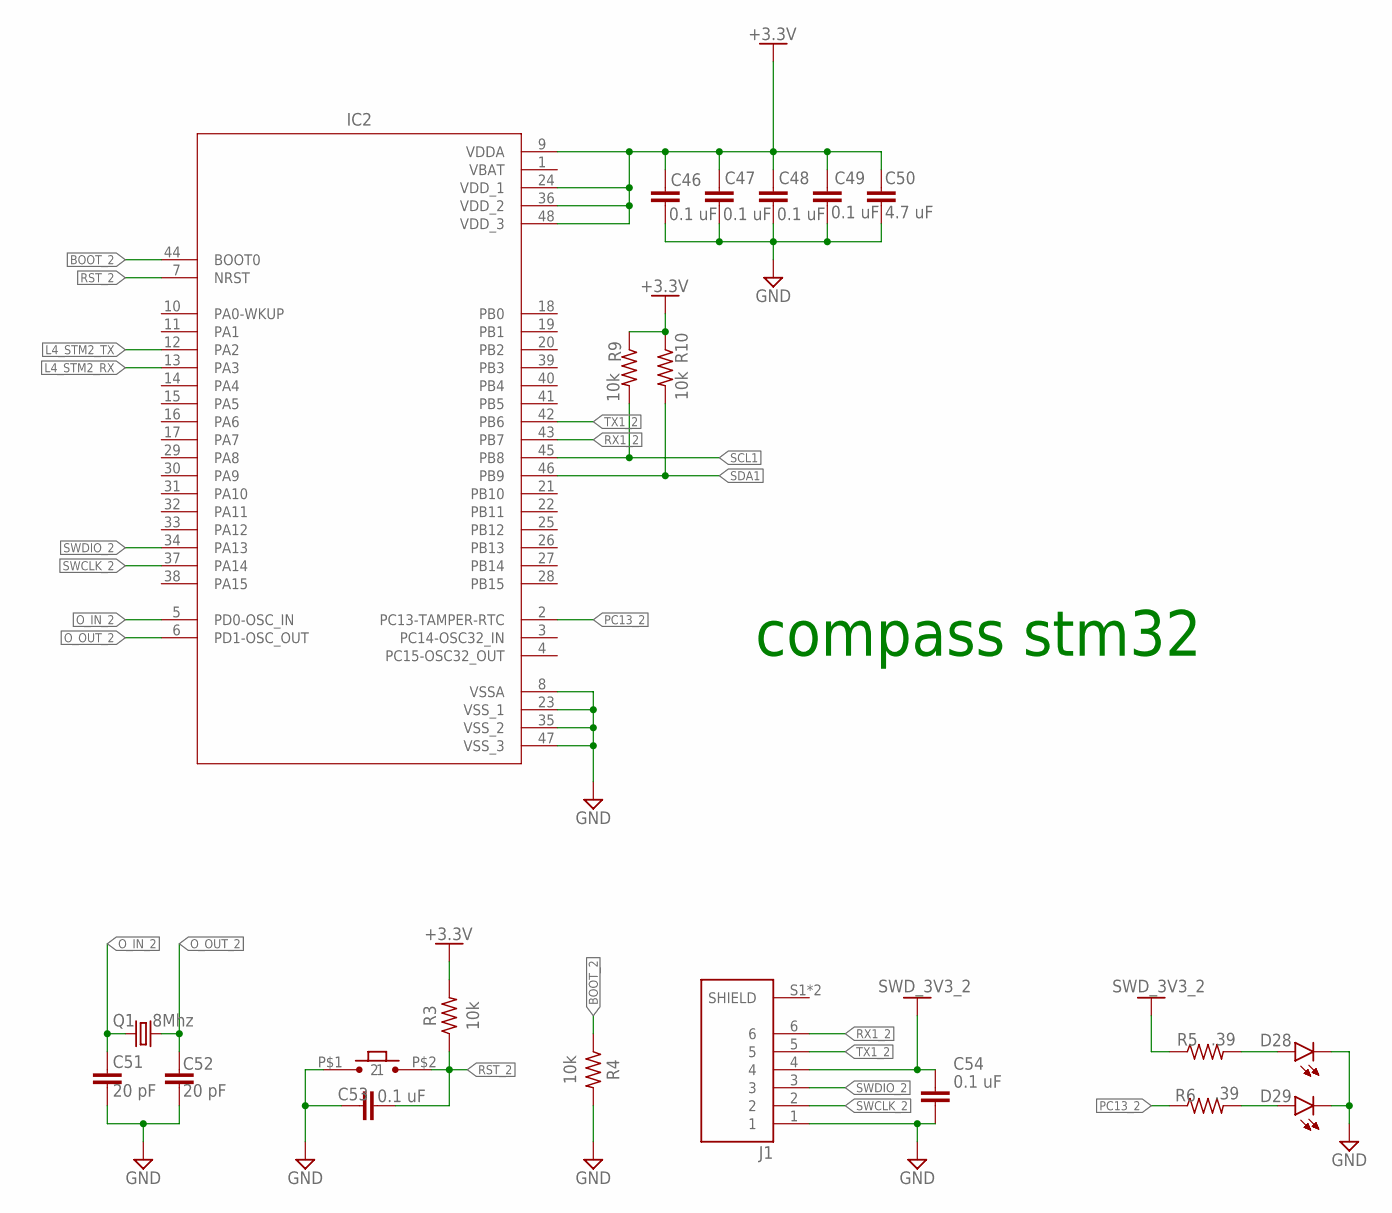
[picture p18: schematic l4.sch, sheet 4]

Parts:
C46, C47, C48, C49, C53, C54: 0.1 uF; CAPC1608X85
C50: 4.7 uF; CAPC1608X85
C51, C52: 20 pF; CAPC1608X85
D28, D29: CHIP-FLAT-G_0603-0.35MM; LEDC1608X35N_FLAT-G
IC2: STM32F103_QFP; QFP50P900X900X160-48N
J1: SM06B-SRSS-TB(LF)(SN); JST_SM06B-SRSS-TB(LF)(SN)
Q1: 8Mhz; CTS406
R3, R4, R9, R10: 10k; RESC1608X60
R5, R6: .39; RESC1608X60
U$2: SMOL_TACTILE_3X4MM

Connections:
+3.3V: C46.1, C47.1, C48.1, C49.1, C50.1, IC2.9 (VDDA), IC2.24 (VDD_1), IC2.36 (VDD_2), IC2.48 (VDD_3), R3.2, R9.1, R10.1; also elsewhere on the board
BOOT_2: IC2.44 (BOOT0), R4.1
GND: C46.2, C47.2, C48.2, C49.2, C50.2, C51.2, C52.2, C53.1, C54.2, D28.C, D29.C, IC2.8 (VSSA), IC2.23 (VSS_1), IC2.35 (VSS_2), IC2.47 (VSS_3), J1.1, R4.2, U$2.P$1 (1); also elsewhere on the board
L4_STM2_RX: IC2.13 (PA3); also elsewhere on the board
L4_STM2_TX: IC2.12 (PA2); also elsewhere on the board
unnamed: D28.A, R5.2
unnamed: D29.A, R6.2
O_IN_2: C51.1, IC2.5 (PD0-OSC_IN), Q1.1
O_OUT_2: C52.1, IC2.6 (PD1-OSC_OUT), Q1.3 (2)
PC13_2: IC2.2 (PC13-TAMPER-RTC), R6.1
RST_2: C53.2, IC2.7 (NRST), R3.1, U$2.P$2 (2)
RX1_2: IC2.43 (PB7), J1.6
SCL1: IC2.45 (PB8), R9.2; also elsewhere on the board
SDA1: IC2.46 (PB9), R10.2; also elsewhere on the board
SWCLK_2: IC2.37 (PA14), J1.2
SWDIO_2: IC2.34 (PA13), J1.3
SWD_3V3_2: C54.1, J1.4, R5.1
TX1_2: IC2.42 (PB6), J1.5
VBAT: IC2.1 (VBAT); also elsewhere on the board

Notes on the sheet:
compass stm32

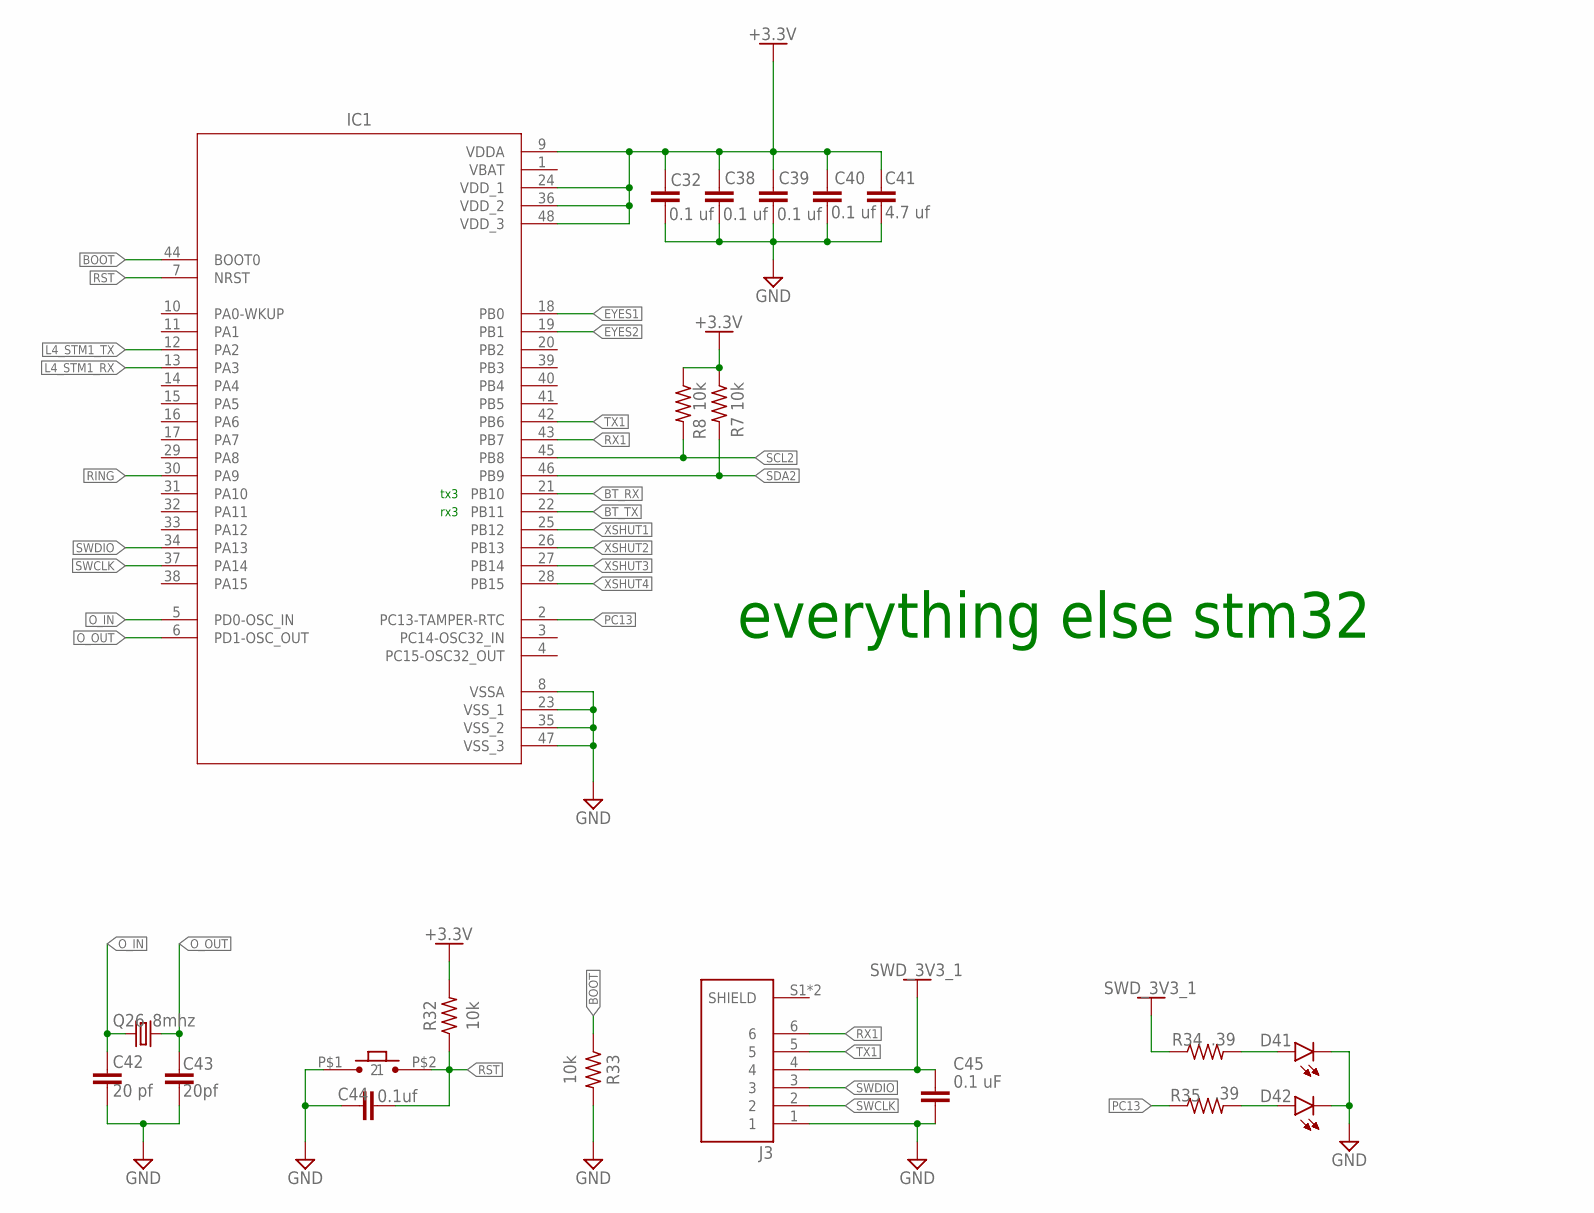
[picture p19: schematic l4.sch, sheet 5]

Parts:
C32, C38, C39, C40: 0.1 uf; CAPC1608X85
C41: 4.7 uf; CAPC1608X85
C42: 20 pf; CAPC1608X85
C43: 20pf; CAPC1608X85
C44: 0.1uf; CAPC1608X85
C45: 0.1 uF; CAPC1608X85
D41, D42: CHIP-FLAT-G_0603-0.35MM; LEDC1608X35N_FLAT-G
IC1: STM32F103_QFP; QFP50P900X900X160-48N
J3: SM06B-SRSS-TB(LF)(SN); JST_SM06B-SRSS-TB(LF)(SN)
Q26: 8mhz; CTS406
R7, R8, R32, R33: 10k; RESC1608X60
R34, R35: .39; RESC1608X60
U$1: SMOL_TACTILE_3X4MM

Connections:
+3.3V: C32.1, C38.1, C39.1, C40.1, C41.1, IC1.9 (VDDA), IC1.24 (VDD_1), IC1.36 (VDD_2), IC1.48 (VDD_3), R7.1, R8.1, R32.2; also elsewhere on the board
BOOT: IC1.44 (BOOT0), R33.1
BT_RX: IC1.21 (PB10); also elsewhere on the board
BT_TX: IC1.22 (PB11); also elsewhere on the board
EYES1: IC1.18 (PB0); also elsewhere on the board
EYES2: IC1.19 (PB1); also elsewhere on the board
GND: C32.2, C38.2, C39.2, C40.2, C41.2, C42.2, C43.2, C44.1, C45.2, D41.C, D42.C, IC1.8 (VSSA), IC1.23 (VSS_1), IC1.35 (VSS_2), IC1.47 (VSS_3), J3.1, R33.2, U$1.P$1 (1); also elsewhere on the board
L4_STM1_RX: IC1.13 (PA3); also elsewhere on the board
L4_STM1_TX: IC1.12 (PA2); also elsewhere on the board
unnamed: D41.A, R34.2
unnamed: D42.A, R35.2
O_IN: C42.1, IC1.5 (PD0-OSC_IN), Q26.1
O_OUT: C43.1, IC1.6 (PD1-OSC_OUT), Q26.3 (2)
PC13: IC1.2 (PC13-TAMPER-RTC), R35.1
RING: IC1.30 (PA9); also elsewhere on the board
RST: C44.2, IC1.7 (NRST), R32.1, U$1.P$2 (2)
RX1: IC1.43 (PB7), J3.6
SCL2: IC1.45 (PB8), R8.2; also elsewhere on the board
SDA2: IC1.46 (PB9), R7.2; also elsewhere on the board
SWCLK: IC1.37 (PA14), J3.2
SWDIO: IC1.34 (PA13), J3.3
SWD_3V3_1: C45.1, J3.4, R34.1
TX1: IC1.42 (PB6), J3.5
VBAT: IC1.1 (VBAT); also elsewhere on the board
XSHUT1: IC1.25 (PB12); also elsewhere on the board
XSHUT2: IC1.26 (PB13); also elsewhere on the board
XSHUT3: IC1.27 (PB14); also elsewhere on the board
XSHUT4: IC1.28 (PB15); also elsewhere on the board

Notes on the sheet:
everything else stm32
tx3
rx3

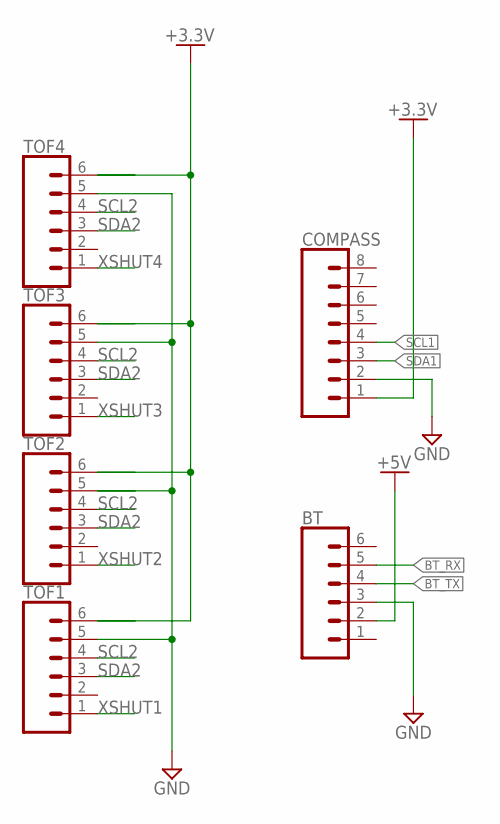
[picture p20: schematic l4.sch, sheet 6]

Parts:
BT: CONN_06LOCK; 1X06_LOCK
COMPASS: CONN_08LOCK; 1X08_LOCK
TOF1, TOF2, TOF3, TOF4: CONN_06LOCK; 1X06_LOCK

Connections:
+3.3V: COMPASS.1, TOF1.6, TOF2.6, TOF3.6, TOF4.6; also elsewhere on the board
+5V: BT.2; also elsewhere on the board
BT_RX: BT.5; also elsewhere on the board
BT_TX: BT.4; also elsewhere on the board
GND: BT.3, COMPASS.2, TOF1.5, TOF2.5, TOF3.5, TOF4.5; also elsewhere on the board
SCL1: COMPASS.4; also elsewhere on the board
SCL2: TOF1.4, TOF2.4, TOF3.4, TOF4.4; also elsewhere on the board
SDA1: COMPASS.3; also elsewhere on the board
SDA2: TOF1.3, TOF2.3, TOF3.3, TOF4.3; also elsewhere on the board
XSHUT1: TOF1.1; also elsewhere on the board
XSHUT2: TOF2.1; also elsewhere on the board
XSHUT3: TOF3.1; also elsewhere on the board
XSHUT4: TOF4.1; also elsewhere on the board

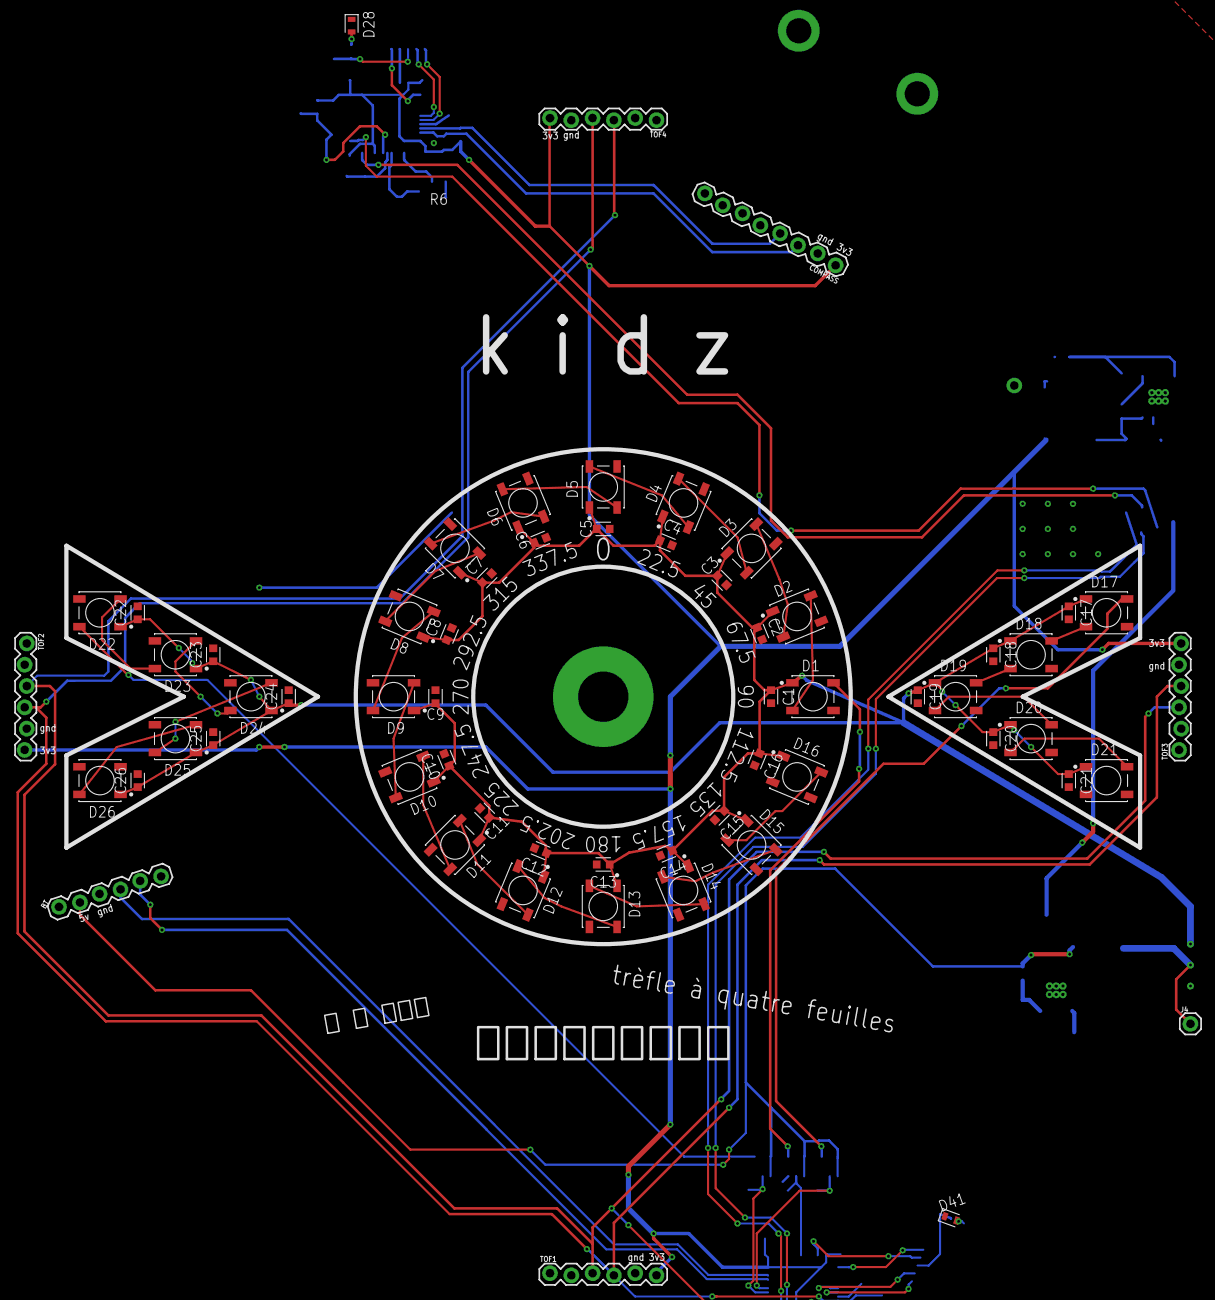
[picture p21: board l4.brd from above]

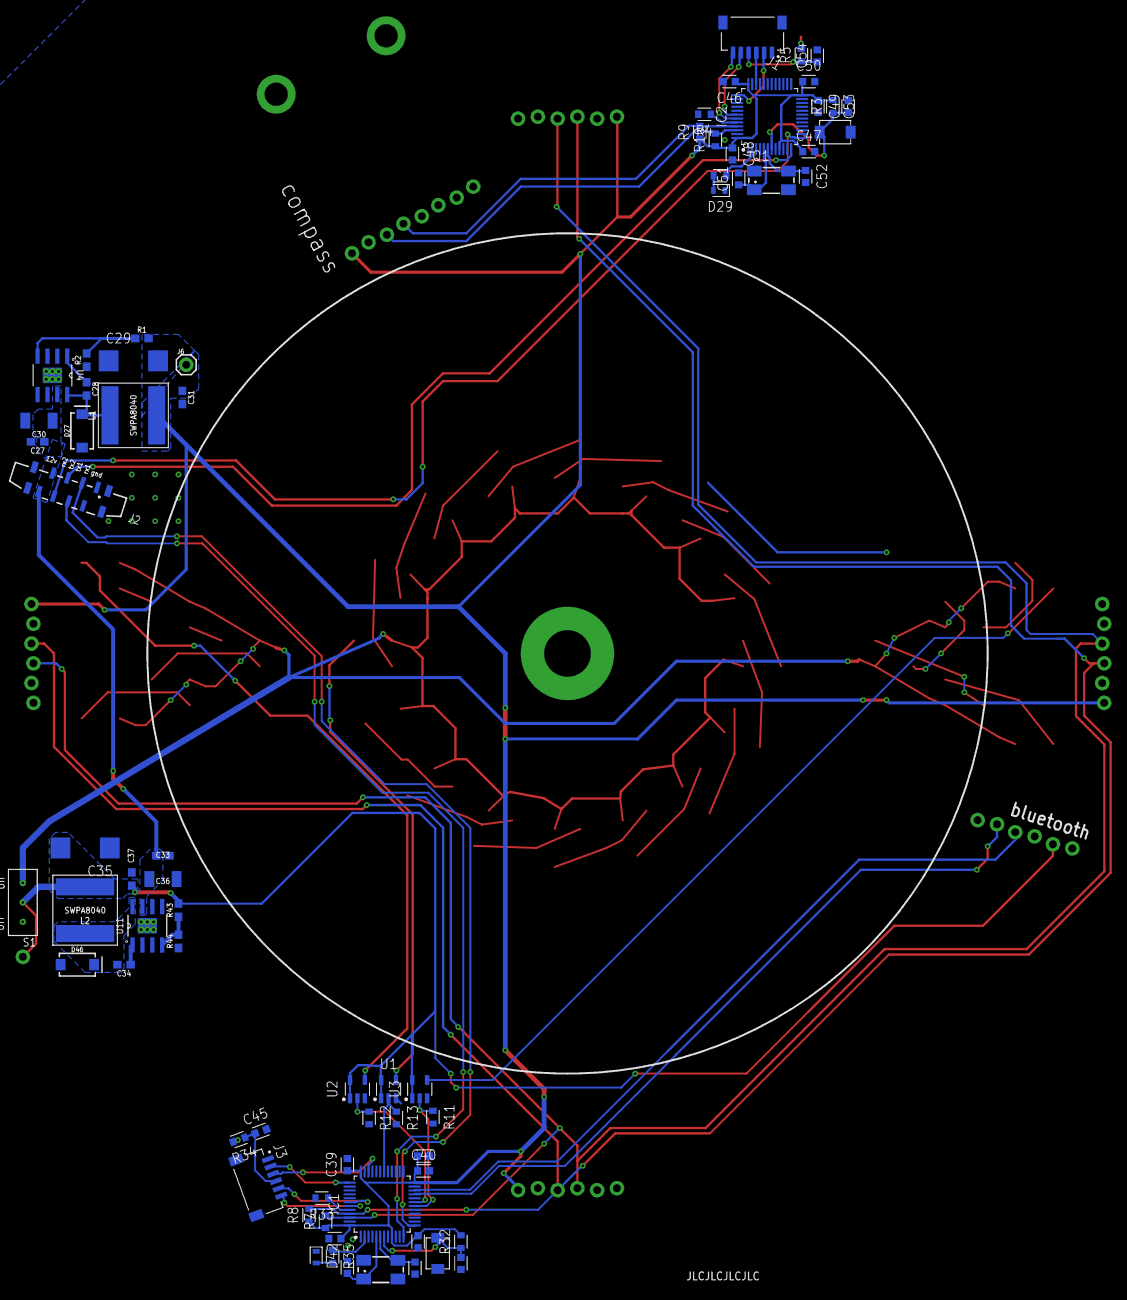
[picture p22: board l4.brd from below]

Board: 2 copper layers, 130 parts (69 on the bottom side), 79 nets.

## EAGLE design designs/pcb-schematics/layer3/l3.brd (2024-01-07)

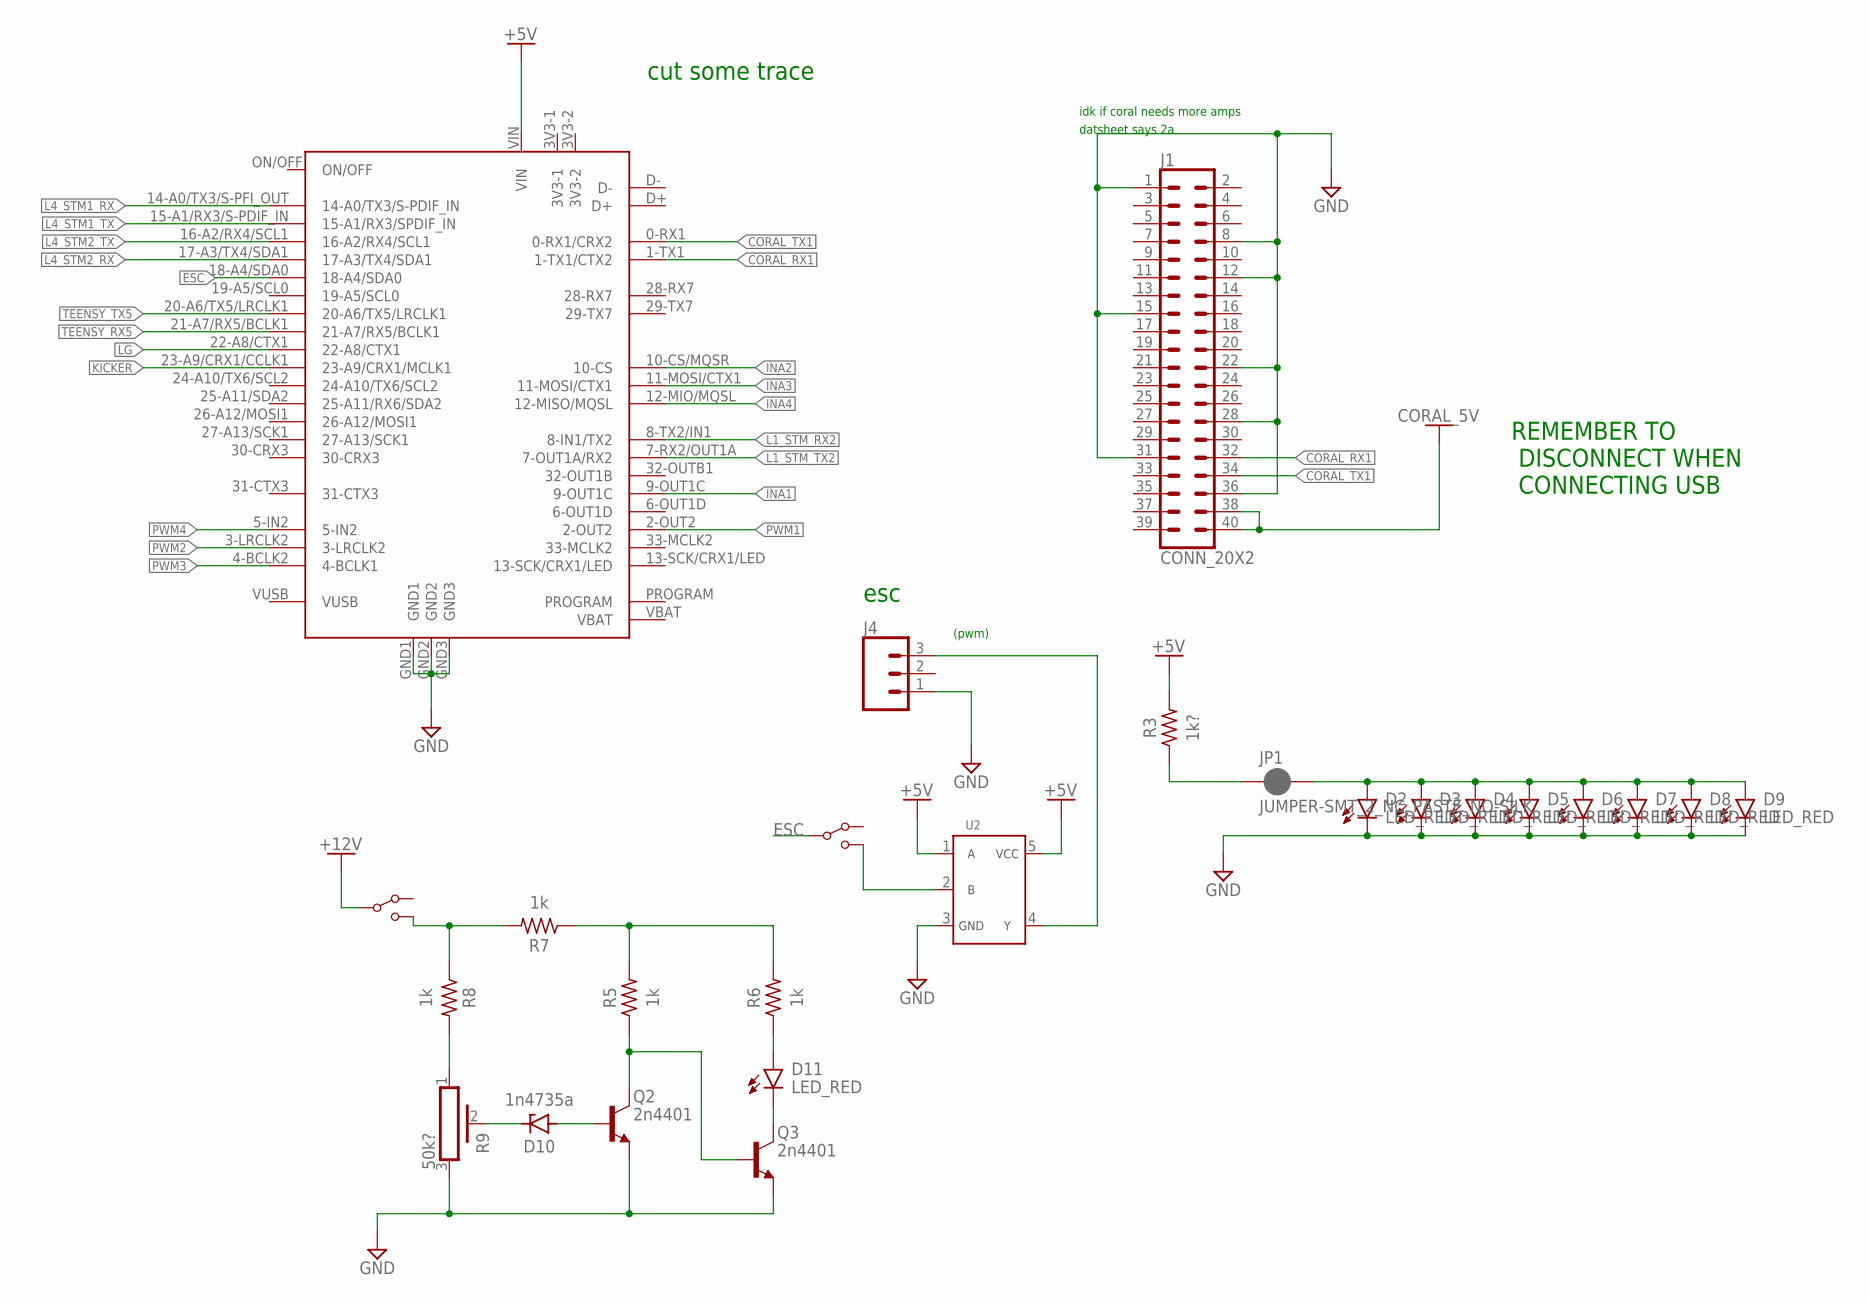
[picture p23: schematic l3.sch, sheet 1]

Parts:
D2, D3, D4, D5, D6, D7, D8, D9, D11: LED_RED; LEDC1608X55N_FLAT-R
D10: 1n4735a; DO41
J1: CONN_20X2; 2X20
J4: CONN_03LOCK; 1X03_LOCK
JP1: JUMPER-SMT_2_NC_PASTE_NO-SILK; SMT-JUMPER_2_NC_PASTE_NO-SILK
Q2, Q3: 2n4401; TO92
R3: 1k?; RESC1608X60
R5, R6, R7, R8: 1k; RESC1608X60
R9: 50k?; PV36X
S1, S2: SPDT-SLIDE-SWITCHSWITCH-TH; SWITCH-TH
U2: SN74AHCT1G08; SOT23-5
U$1: TEENSY40

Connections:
+5V: R3.2, U2.1, U2.5, U$1.VIN; also elsewhere on the board
+12V: S1.P$2; also elsewhere on the board
CORAL_5V: J1.38, J1.40; also elsewhere on the board
CORAL_RX1: J1.32, U$1.1-TX1 (1-TX1/CTX2)
CORAL_TX1: J1.34, U$1.0-RX1 (0-RX1/CRX2)
ESC: S2.P$2, U$1.18-A4/SDA0
GND: D2.C, D3.C, D4.C, D5.C, D6.C, D7.C, D8.C, D9.C, J1.1, J1.8, J1.12, J1.15, J1.22, J1.28, J1.31, J1.36, J4.1, Q2.1 (E), Q3.1 (E), R9.3, U2.3, U$1.GND1, U$1.GND2, U$1.GND3; also elsewhere on the board
INA1: U$1.9-OUT1C; also elsewhere on the board
INA2: U$1.10-CS/MQSR (10-CS); also elsewhere on the board
INA3: U$1.11-MOSI/CTX1; also elsewhere on the board
INA4: U$1.12-MIO/MQSL (12-MISO/MQSL); also elsewhere on the board
KICKER: U$1.23-A9/CRX1/CCLK1 (23-A9/CRX1/MCLK1); also elsewhere on the board
L1_STM_RX2: U$1.8-TX2/IN1 (8-IN1/TX2); also elsewhere on the board
L1_STM_TX2: U$1.7-RX2/OUT1A (7-OUT1A/RX2); also elsewhere on the board
L4_STM1_RX: U$1.14-A0/TX3/S-PFI_OUT (14-A0/TX3/S-PDIF_IN); also elsewhere on the board
L4_STM1_TX: U$1.15-A1/RX3/S-PDIF_IN (15-A1/RX3/SPDIF_IN); also elsewhere on the board
L4_STM2_RX: U$1.17-A3/TX4/SDA1; also elsewhere on the board
L4_STM2_TX: U$1.16-A2/RX4/SCL1; also elsewhere on the board
LG: U$1.22-A8/CTX1; also elsewhere on the board
unnamed: D2.A, D3.A, D4.A, D5.A, D6.A, D7.A, D8.A, D9.A, JP1.2
unnamed: JP1.1, R3.1
unnamed: D10.C, R9.2
unnamed: D10.A, Q2.2 (B)
unnamed: Q2.3 (C), Q3.2 (B), R5.1
unnamed: R8.2, R9.1
unnamed: R5.2, R6.2, R7.1
unnamed: D11.A, R6.1
unnamed: D11.C, Q3.3 (C)
unnamed: R7.2, R8.1, S1.P$3
unnamed: S2.P$3, U2.2
unnamed: J4.3, U2.4
PWM1: U$1.2-OUT2; also elsewhere on the board
PWM2: U$1.3-LRCLK2; also elsewhere on the board
PWM3: U$1.4-BCLK2 (4-BCLK1); also elsewhere on the board
PWM4: U$1.5-IN2; also elsewhere on the board
TEENSY_RX5: U$1.21-A7/RX5/BCLK1
TEENSY_TX5: U$1.20-A6/TX5/LRCLK1

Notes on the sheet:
idk if coral needs more amps
datsheet says 2a
REMEMBER TO DISCONNECT WHEN CONNECTING USB
cut some trace
esc
(pwm)

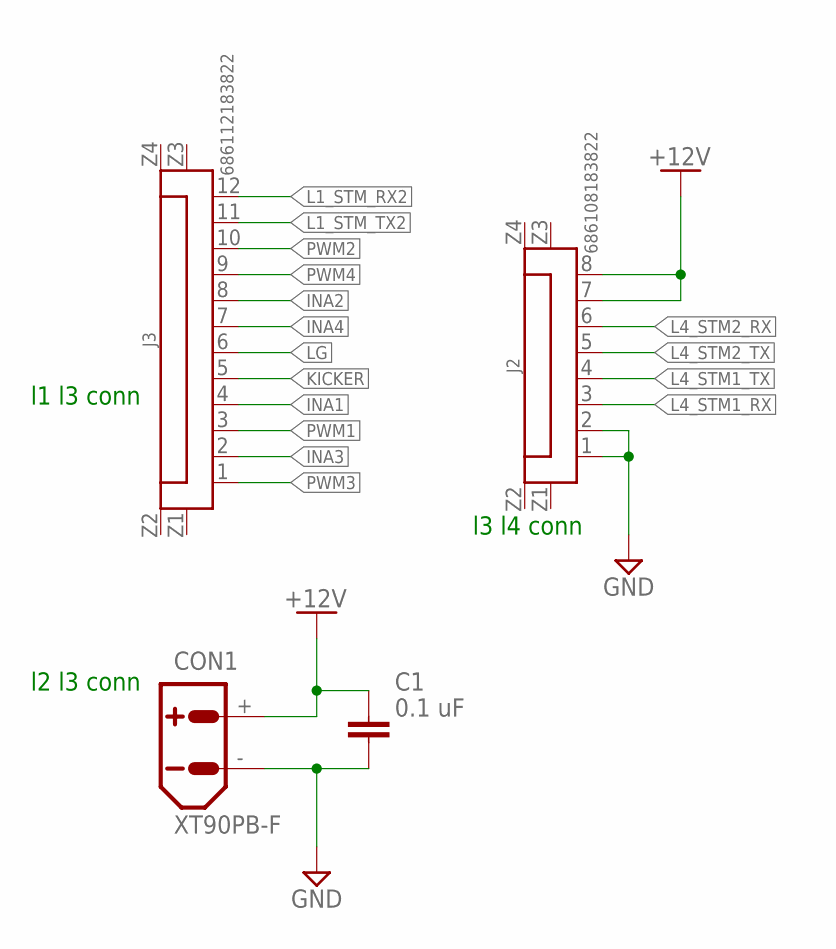
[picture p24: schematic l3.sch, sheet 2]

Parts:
C1: 0.1 uF; CAPC1608X85
CON1: XT90PB-F
J2: 686108183822
J3: 686112183822

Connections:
+12V: C1.1, CON1.+, J2.7, J2.8; also elsewhere on the board
GND: C1.2, CON1.-, J2.1, J2.2; also elsewhere on the board
INA1: J3.4; also elsewhere on the board
INA2: J3.8; also elsewhere on the board
INA3: J3.2; also elsewhere on the board
INA4: J3.7; also elsewhere on the board
KICKER: J3.5; also elsewhere on the board
L1_STM_RX2: J3.12; also elsewhere on the board
L1_STM_TX2: J3.11; also elsewhere on the board
L4_STM1_RX: J2.3; also elsewhere on the board
L4_STM1_TX: J2.4; also elsewhere on the board
L4_STM2_RX: J2.6; also elsewhere on the board
L4_STM2_TX: J2.5; also elsewhere on the board
LG: J3.6; also elsewhere on the board
PWM1: J3.3; also elsewhere on the board
PWM2: J3.10; also elsewhere on the board
PWM3: J3.1; also elsewhere on the board
PWM4: J3.9; also elsewhere on the board

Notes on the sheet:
l2 l3 conn
l1 l3 conn
l3 l4 conn

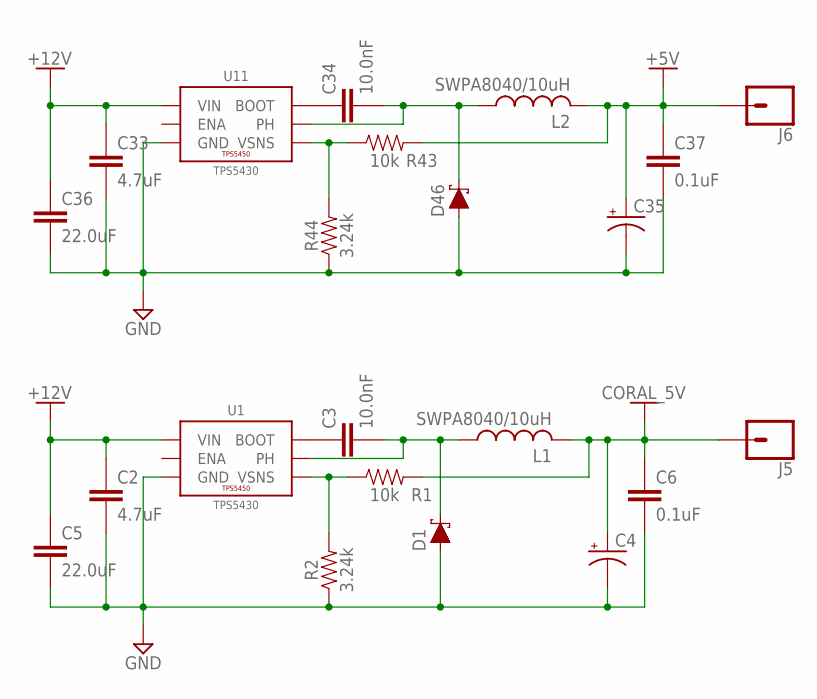
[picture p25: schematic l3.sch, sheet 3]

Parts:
C2, C33: 4.7uF; C0603
C3, C34: 10.0nF; C0603
C4, C35: 220uF; D/7343-31R
C5, C36: 22.0uF; C1210
C6, C37: 0.1uF; C0603
D1, D46: 3A/40V/500mV; SMA-DIODE
J5, J6: CONN_01; 1X01
L1, L2: SWPA8040/10uH; SWPA8040
R1, R43: 10k; R0603
R2, R44: 3.24k; R0603
U1, U11: TPS5430; POWERPAD-SOIC-8

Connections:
+5V: C35.+, C37.1, J6.1, L2.P2 (2), R43.2; also elsewhere on the board
+12V: C2.1, C5.1, C33.1, C36.1, U1.7 (VIN), U11.7 (VIN); also elsewhere on the board
CORAL_5V: C4.+, C6.1, J5.1, L1.P2 (2), R1.2; also elsewhere on the board
GND: C2.2, C4.-, C5.2, C6.2, C33.2, C35.-, C36.2, C37.2, D1.A, D46.A, R2.1, R44.1, U1.6 (GND), U1.9 (GND), U1.P$1 (GND), U1.P$2 (GND), U1.P$3 (GND), U1.P$4 (GND), U1.P$5 (GND), U1.P$6 (GND), U11.6 (GND), U11.9 (GND), U11.P$1 (GND), U11.P$2 (GND), U11.P$3 (GND), U11.P$4 (GND), U11.P$5 (GND), U11.P$6 (GND); also elsewhere on the board
unnamed: C3.2, D1.C, L1.P1 (1), U1.8 (PH)
unnamed: R1.1, R2.2, U1.4 (VSNS)
unnamed: C3.1, U1.1 (BOOT)
unnamed: C34.2, D46.C, L2.P1 (1), U11.8 (PH)
unnamed: R43.1, R44.2, U11.4 (VSNS)
unnamed: C34.1, U11.1 (BOOT)

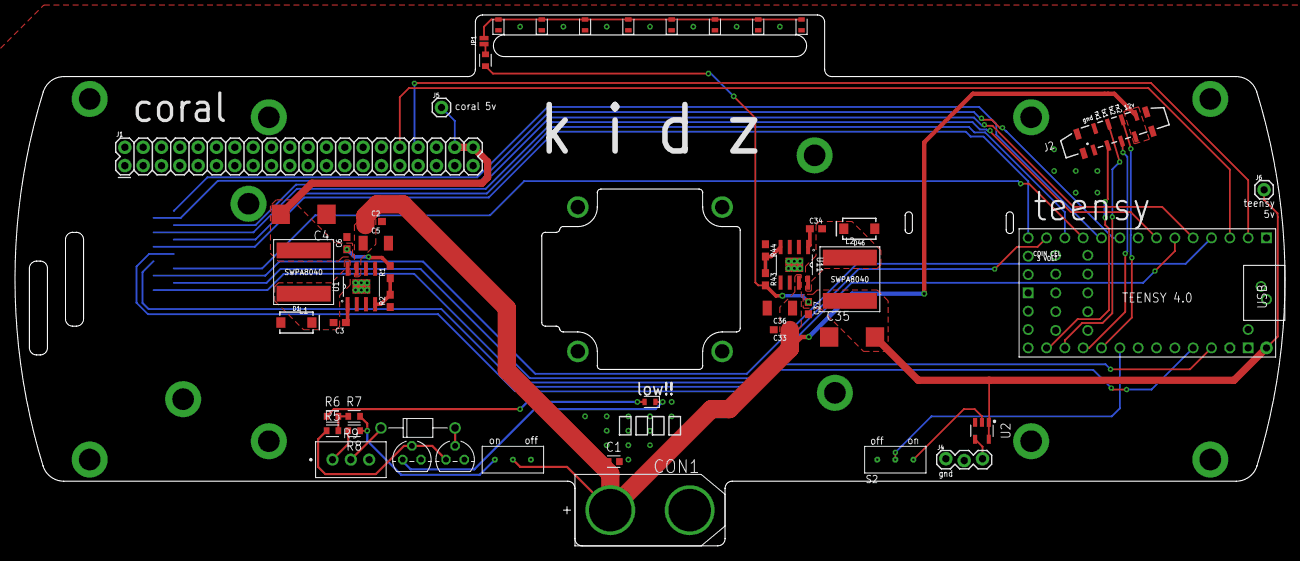
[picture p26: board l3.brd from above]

Board: 2 copper layers, 176.0 x 73.6 mm, 51 parts (1 on the bottom side), 41 nets.

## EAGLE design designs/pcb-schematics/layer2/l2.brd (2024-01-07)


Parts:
C1, C2, C3, C31, C32: 0.1 uF; CAPC1608X85
CON1: XT90PB-M
CON2, CON3, CON4: XT60PB-M
CON5: XT30UPB-M

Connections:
12V: C1.1, C3.1, C31.1, CON1.+, CON3.+, CON5.+
BATT_12V: C2.1, CON4.+
GND: C1.2, C2.2, C3.2, C31.2, C32.2, CON1.-, CON2.-, CON3.-, CON4.-, CON5.-
MOTOR_12V: C32.1, CON2.+

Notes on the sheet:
motor power
everything else
l2 l3 connection
batt
esc

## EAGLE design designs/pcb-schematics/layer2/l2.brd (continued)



Board: 2 copper layers, 82.4 x 63.0 mm, 10 parts (5 on the bottom side), 4 nets.

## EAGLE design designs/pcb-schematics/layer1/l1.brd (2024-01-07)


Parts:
C1, C2, C3: 0.1 uF; CAPC1608X85
D1, D2, D3, D4, D5, D6, D7, D8, D9, D10, D11, D12, D13, D14, D15, D16, D17, D18, D19, D20, D21, D22, D23, D24, D25, D26, D27, D28, D29, D30, D31, D32: OF-SMD3528WCLED; LED
J1, J2: CONN_02; 1X02
JP1: JUMPER-SMT_3_NO_SILK; SMT-JUMPER_3_NO_SILK
P1, P2, P3, P4, P5, P6, P7, P9, P10, P12, P13, P14, P15, P16, P17, P18, P19, P20, P21, P22, P23, P24, P25, P26, P27, P28, P29, P30, P31, P32: EVERLIGHT_ALS-PT19-315C-L177-TR8; ALS-PT19
R1: 100; RESC1608X60
R2, R3, R4, R5, R7: 10k; RESC1608X60
S1: SPDT-SLIDE-SWITCHSWITCH-TH; SWITCH-TH
U1, U2: 74HC4067SM96; SSOP24

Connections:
1S0: U1.10 (S0); also elsewhere on the board
1S1: U1.11 (S1); also elsewhere on the board
1S2: U1.14 (S2); also elsewhere on the board
1S3: U1.13 (S3); also elsewhere on the board
2S0: U2.10 (S0); also elsewhere on the board
2S1: U2.11 (S1); also elsewhere on the board
2S2: U2.14 (S2); also elsewhere on the board
2S3: U2.13 (S3); also elsewhere on the board
+3.3V: C1.1, C2.1, C3.1, J2.2, JP1.1, P1.2 (EMITTER), P2.2 (EMITTER), P3.2 (EMITTER), P4.2 (EMITTER), P5.2 (EMITTER), P6.2 (EMITTER), P7.2 (EMITTER), P9.2 (EMITTER), P10.2 (EMITTER), P12.2 (EMITTER), P13.2 (EMITTER), P14.2 (EMITTER), P15.2 (EMITTER), P16.2 (EMITTER), P17.2 (EMITTER), P18.2 (EMITTER), P19.2 (EMITTER), P20.2 (EMITTER), P21.2 (EMITTER), P22.2 (EMITTER), P23.2 (EMITTER), P24.2 (EMITTER), P25.2 (EMITTER), P26.2 (EMITTER), P27.2 (EMITTER), P28.2 (EMITTER), P29.2 (EMITTER), P30.2 (EMITTER), P31.2 (EMITTER), P32.2 (EMITTER), U1.24 (VCC), U2.24 (VCC); also elsewhere on the board
+5V: JP1.3; also elsewhere on the board
COM1: R2.2, U1.1 (COM); also elsewhere on the board
COM2: R4.2, U2.1 (COM); also elsewhere on the board
GND: C1.2, C2.2, C3.2, D1.2 (C), D2.2 (C), D3.2 (C), D4.2 (C), D5.2 (C), D6.2 (C), D7.2 (C), D8.2 (C), D9.2 (C), D10.2 (C), D11.2 (C), D12.2 (C), D13.2 (C), D14.2 (C), D15.2 (C), D16.2 (C), D17.2 (C), D18.2 (C), D19.2 (C), D20.2 (C), D21.2 (C), D22.2 (C), D23.2 (C), D24.2 (C), D25.2 (C), D26.2 (C), D27.2 (C), D28.2 (C), D29.2 (C), D30.2 (C), D31.2 (C), D32.2 (C), J1.1, R2.1, R3.1, R4.1, R5.1, R7.1, U1.12 (GND), U2.12 (GND); also elsewhere on the board
LG: J2.1, R7.2; also elsewhere on the board
unnamed: JP1.2, S1.P$1
unnamed: R3.2, U1.15 (EN)
unnamed: D1.1 (A), D2.1 (A), D3.1 (A), D4.1 (A), D5.1 (A), D6.1 (A), D7.1 (A), D8.1 (A), D9.1 (A), D10.1 (A), D11.1 (A), D12.1 (A), D13.1 (A), D14.1 (A), D15.1 (A), D16.1 (A), D17.1 (A), D18.1 (A), D19.1 (A), D20.1 (A), D21.1 (A), D22.1 (A), D23.1 (A), D24.1 (A), D25.1 (A), D26.1 (A), D27.1 (A), D28.1 (A), D29.1 (A), D30.1 (A), D31.1 (A), D32.1 (A), J1.2, R1.1
unnamed: R5.2, U2.15 (EN)
unnamed: R1.2, S1.P$2
unnamed: P25.1 (COLLECTOR), U1.8 (CHAN1)
unnamed: P17.1 (COLLECTOR), U1.22 (CHAN9)
unnamed: P18.1 (COLLECTOR), U1.23 (CHAN8)
unnamed: P19.1 (COLLECTOR), U1.2 (CHAN7)
unnamed: P20.1 (COLLECTOR), U1.3 (CHAN6)
unnamed: P21.1 (COLLECTOR), U1.4 (CHAN5)
unnamed: P22.1 (COLLECTOR), U1.5 (CHAN4)
unnamed: P23.1 (COLLECTOR), U1.6 (CHAN3)
unnamed: P24.1 (COLLECTOR), U1.7 (CHAN2)
unnamed: P10.1 (COLLECTOR), U1.16 (CHAN15)
unnamed: P12.1 (COLLECTOR), U1.17 (CHAN14)
unnamed: P13.1 (COLLECTOR), U1.18 (CHAN13)
unnamed: P14.1 (COLLECTOR), U1.19 (CHAN12)
unnamed: P15.1 (COLLECTOR), U1.20 (CHAN11)
unnamed: P16.1 (COLLECTOR), U1.21 (CHAN10)
unnamed: P9.1 (COLLECTOR), U2.8 (CHAN1)
unnamed: P1.1 (COLLECTOR), U2.23 (CHAN8)
unnamed: P2.1 (COLLECTOR), U2.2 (CHAN7)
unnamed: P3.1 (COLLECTOR), U2.3 (CHAN6)
unnamed: P4.1 (COLLECTOR), U2.4 (CHAN5)
unnamed: P5.1 (COLLECTOR), U2.5 (CHAN4)
unnamed: P6.1 (COLLECTOR), U2.6 (CHAN3)
unnamed: P7.1 (COLLECTOR), U2.7 (CHAN2)
unnamed: P26.1 (COLLECTOR), U2.16 (CHAN15)
unnamed: P27.1 (COLLECTOR), U2.17 (CHAN14)
unnamed: P28.1 (COLLECTOR), U2.18 (CHAN13)
unnamed: P29.1 (COLLECTOR), U2.19 (CHAN12)
unnamed: P30.1 (COLLECTOR), U2.20 (CHAN11)
unnamed: P31.1 (COLLECTOR), U2.21 (CHAN10)
unnamed: P32.1 (COLLECTOR), U2.22 (CHAN9)

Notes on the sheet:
lightgate led
lightgate ldr


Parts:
C4, C5, C6, C7, C19, C20: 0.1 uF; CAPC1608X85
C8: 4.7 uF; CAPC1608X85
C9, C10: 20 pF; CAPC1608X85
D41, D42: CHIP-FLAT-G_0603-0.35MM; LEDC1608X35N_FLAT-G
IC1: STM32F103_QFP; QFP50P900X900X160-48N
J3: SM06B-SRSS-TB(LF)(SN); JST_SM06B-SRSS-TB(LF)(SN)
Q26: 8Mhz; CTS406
R32, R33: 10k; RESC1608X60
R34, R35: 100; RESC1608X60
U$1: SMOL_TACTILE_3X4MM

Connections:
1S0: IC1.31 (PA10); also elsewhere on the board
1S1: IC1.30 (PA9); also elsewhere on the board
1S2: IC1.32 (PA11); also elsewhere on the board
1S3: IC1.33 (PA12); also elsewhere on the board
2S0: IC1.17 (PA7); also elsewhere on the board
2S1: IC1.16 (PA6); also elsewhere on the board
2S2: IC1.15 (PA5); also elsewhere on the board
2S3: IC1.14 (PA4); also elsewhere on the board
+3.3V: C4.1, C5.1, C6.1, C7.1, C8.1, IC1.9 (VDDA), IC1.24 (VDD_1), IC1.36 (VDD_2), IC1.48 (VDD_3), R32.2; also elsewhere on the board
BOOT: IC1.44 (BOOT0), R33.1
COM1: IC1.18 (PB0); also elsewhere on the board
COM2: IC1.19 (PB1); also elsewhere on the board
GND: C4.2, C5.2, C6.2, C7.2, C8.2, C9.2, C10.2, C19.1, C20.2, D41.C, D42.C, IC1.8 (VSSA), IC1.23 (VSS_1), IC1.35 (VSS_2), IC1.47 (VSS_3), J3.1, R33.2, U$1.P$1 (1); also elsewhere on the board
LG: IC1.11 (PA1); also elsewhere on the board
unnamed: D41.A, R34.2
unnamed: D42.A, R35.2
O_IN: C9.1, IC1.5 (PD0-OSC_IN), Q26.1
O_OUT: C10.1, IC1.6 (PD1-OSC_OUT), Q26.3 (2)
PC13: IC1.2 (PC13-TAMPER-RTC), R35.1
RST: C19.2, IC1.7 (NRST), R32.1, U$1.P$2 (2)
RX1: IC1.43 (PB7), J3.6
RX2: IC1.13 (PA3); also elsewhere on the board
SWCLK: IC1.37 (PA14), J3.2
SWDIO: IC1.34 (PA13), J3.3
SWD_3V3: C20.1, J3.4, R34.1
TX1: IC1.42 (PB6), J3.5
TX2: IC1.12 (PA2); also elsewhere on the board
VBAT: IC1.1 (VBAT)


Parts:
C11, C14, C16, C18: 470 uF; 6.3_X_7.7
C12, C13, C15, C17: 0.1 uF; CAPC1608X85
CON1, CON2, CON3, CON4: XT30UPB-M
D33, D34, D35, D36, D37, D38, D39, D40: CHIP-FLAT-G_0603-0.35MM; LEDC1608X35N_FLAT-G
R8, R9, R10, R11, R13, R14, R15, R16, R18, R19, R20, R21, R23, R24, R25, R26: 1k; RESC1608X60
R12, R17, R22, R27: 10k; RESC1608X60
R28, R29: ?; RESC1608X60
R30, R31: 20; RESC1608X60
U3, U4: SN74LVC2G04DBVR; SOT23-6
U5, U6, U7, U8: VNH5050A-E; SOP50P1030X247-39N

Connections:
+3.3V: R8.2, R9.2, R13.2, R14.2, R18.2, R19.2, R23.2, R24.2, U3.5, U4.5; also elsewhere on the board
GND: C11.2, C12.2, C13.2, C14.2, C15.2, C16.2, C17.2, C18.2, U3.2, U4.2, U5.1 (GND_A), U5.3 (GND_A), U5.4 (GND_A), U5.5 (GND_A), U5.6 (GND_A), U5.7 (GND_A), U5.30 (GND_B), U5.31 (GND_B), U5.32 (GND_B), U5.33 (GND_B), U5.34 (GND_B), U5.36 (GND_B), U6.1 (GND_A), U6.3 (GND_A), U6.4 (GND_A), U6.5 (GND_A), U6.6 (GND_A), U6.7 (GND_A), U6.30 (GND_B), U6.31 (GND_B), U6.32 (GND_B), U6.33 (GND_B), U6.34 (GND_B), U6.36 (GND_B), U7.1 (GND_A), U7.3 (GND_A), U7.4 (GND_A), U7.5 (GND_A), U7.6 (GND_A), U7.7 (GND_A), U7.30 (GND_B), U7.31 (GND_B), U7.32 (GND_B), U7.33 (GND_B), U7.34 (GND_B), U7.36 (GND_B), U8.1 (GND_A), U8.3 (GND_A), U8.4 (GND_A), U8.5 (GND_A), U8.6 (GND_A), U8.7 (GND_A), U8.30 (GND_B), U8.31 (GND_B), U8.32 (GND_B), U8.33 (GND_B), U8.34 (GND_B), U8.36 (GND_B); also elsewhere on the board
INA1: R10.1, U3.3; also elsewhere on the board
INA2: R15.1, U4.1; also elsewhere on the board
INA3: R20.1, U3.1; also elsewhere on the board
INA4: R25.1, U4.3; also elsewhere on the board
INB1: R11.1, U3.4
INB2: R16.1, U4.6
INB3: R21.1, U3.6
INB4: R26.1, U4.4
MOTOR_12V: C11.1, C12.1, C13.1, C14.1, C15.1, C16.1, C17.1, C18.1, U5.13 (VCC), U5.24 (VCC), U5.39 (VCC), U5.39_1 (VCC), U5.39_2 (VCC), U5.39_3 (VCC), U5.39_4 (VCC), U5.39_5 (VCC), U5.39_6 (VCC), U5.39_7 (VCC), U5.39_8 (VCC), U5.39_9 (VCC), U5.39_10 (VCC), U5.39_11 (VCC), U5.39_12 (VCC), U6.13 (VCC), U6.24 (VCC), U6.39 (VCC), U6.39_1 (VCC), U6.39_2 (VCC), U6.39_3 (VCC), U6.39_4 (VCC), U6.39_5 (VCC), U6.39_6 (VCC), U6.39_7 (VCC), U6.39_8 (VCC), U6.39_9 (VCC), U6.39_10 (VCC), U6.39_11 (VCC), U6.39_12 (VCC), U7.13 (VCC), U7.24 (VCC), U7.39 (VCC), U7.39_1 (VCC), U7.39_2 (VCC), U7.39_3 (VCC), U7.39_4 (VCC), U7.39_5 (VCC), U7.39_6 (VCC), U7.39_7 (VCC), U7.39_8 (VCC), U7.39_9 (VCC), U7.39_10 (VCC), U7.39_11 (VCC), U7.39_12 (VCC), U8.13 (VCC), U8.24 (VCC), U8.39 (VCC), U8.39_1 (VCC), U8.39_2 (VCC), U8.39_3 (VCC), U8.39_4 (VCC), U8.39_5 (VCC), U8.39_6 (VCC), U8.39_7 (VCC), U8.39_8 (VCC), U8.39_9 (VCC), U8.39_10 (VCC), U8.39_11 (VCC), U8.39_12 (VCC); also elsewhere on the board
unnamed: R10.2, U5.15 (INA)
unnamed: R11.2, U5.22 (INB)
unnamed: R12.2, U5.17 (IN_PWM)
unnamed: R8.1, U5.16 (ENA/DIAGA)
unnamed: R9.1, U5.21 (ENB/DIAGB)
unnamed: D35.C, D36.A, R29.2
unnamed: D33.C, D34.A, R28.2
unnamed: R15.2, U6.15 (INA)
unnamed: R16.2, U6.22 (INB)
unnamed: R17.2, U6.17 (IN_PWM)
unnamed: R13.1, U6.16 (ENA/DIAGA)
unnamed: R14.1, U6.21 (ENB/DIAGB)
unnamed: D37.C, D38.A, R30.2
unnamed: R20.2, U7.15 (INA)
unnamed: R21.2, U7.22 (INB)
unnamed: R22.2, U7.17 (IN_PWM)
unnamed: R18.1, U7.16 (ENA/DIAGA)
unnamed: R19.1, U7.21 (ENB/DIAGB)
unnamed: D39.C, D40.A, R31.2
unnamed: R25.2, U8.15 (INA)
unnamed: R26.2, U8.22 (INB)
unnamed: R27.2, U8.17 (IN_PWM)
unnamed: R23.1, U8.16 (ENA/DIAGA)
unnamed: R24.1, U8.21 (ENB/DIAGB)
OA1: CON1.-, D33.A, D34.C, U5.2 (OUTA), U5.8 (OUTA), U5.9 (OUTA), U5.10 (OUTA), U5.11 (OUTA), U5.12 (OUTA), U5.14 (OUTA), U5.38 (OUTA), U5.38_1 (OUTA), U5.38_2 (OUTA), U5.38_3 (OUTA), U5.38_4 (OUTA), U5.38_5 (OUTA), U5.38_6 (OUTA)
OA2: CON2.-, D37.A, D38.C, U6.2 (OUTA), U6.8 (OUTA), U6.9 (OUTA), U6.10 (OUTA), U6.11 (OUTA), U6.12 (OUTA), U6.14 (OUTA), U6.38 (OUTA), U6.38_1 (OUTA), U6.38_2 (OUTA), U6.38_3 (OUTA), U6.38_4 (OUTA), U6.38_5 (OUTA), U6.38_6 (OUTA)
OA3: CON3.-, D35.A, D36.C, U7.2 (OUTA), U7.8 (OUTA), U7.9 (OUTA), U7.10 (OUTA), U7.11 (OUTA), U7.12 (OUTA), U7.14 (OUTA), U7.38 (OUTA), U7.38_1 (OUTA), U7.38_2 (OUTA), U7.38_3 (OUTA), U7.38_4 (OUTA), U7.38_5 (OUTA), U7.38_6 (OUTA)
OA4: CON4.-, D39.A, D40.C, U8.2 (OUTA), U8.8 (OUTA), U8.9 (OUTA), U8.10 (OUTA), U8.11 (OUTA), U8.12 (OUTA), U8.14 (OUTA), U8.38 (OUTA), U8.38_1 (OUTA), U8.38_2 (OUTA), U8.38_3 (OUTA), U8.38_4 (OUTA), U8.38_5 (OUTA), U8.38_6 (OUTA)
OB1: CON1.+, R28.1, U5.23 (OUTB), U5.25 (OUTB), U5.26 (OUTB), U5.27 (OUTB), U5.28 (OUTB), U5.29 (OUTB), U5.35 (OUTB), U5.37 (OUTB), U5.37_1 (OUTB), U5.37_2 (OUTB), U5.37_3 (OUTB), U5.37_4 (OUTB), U5.37_5 (OUTB), U5.37_6 (OUTB)
OB2: CON2.+, R30.1, U6.23 (OUTB), U6.25 (OUTB), U6.26 (OUTB), U6.27 (OUTB), U6.28 (OUTB), U6.29 (OUTB), U6.35 (OUTB), U6.37 (OUTB), U6.37_1 (OUTB), U6.37_2 (OUTB), U6.37_3 (OUTB), U6.37_4 (OUTB), U6.37_5 (OUTB), U6.37_6 (OUTB)
OB3: CON3.+, R29.1, U7.23 (OUTB), U7.25 (OUTB), U7.26 (OUTB), U7.27 (OUTB), U7.28 (OUTB), U7.29 (OUTB), U7.35 (OUTB), U7.37 (OUTB), U7.37_1 (OUTB), U7.37_2 (OUTB), U7.37_3 (OUTB), U7.37_4 (OUTB), U7.37_5 (OUTB), U7.37_6 (OUTB)
OB4: CON4.+, R31.1, U8.23 (OUTB), U8.25 (OUTB), U8.26 (OUTB), U8.27 (OUTB), U8.28 (OUTB), U8.29 (OUTB), U8.35 (OUTB), U8.37 (OUTB), U8.37_1 (OUTB), U8.37_2 (OUTB), U8.37_3 (OUTB), U8.37_4 (OUTB), U8.37_5 (OUTB), U8.37_6 (OUTB)
PWM1: R12.1; also elsewhere on the board
PWM2: R17.1; also elsewhere on the board
PWM3: R22.1; also elsewhere on the board
PWM4: R27.1; also elsewhere on the board


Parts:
C21: 1500 pF; CAPC1608X85
C22: 1 uF; CAPC1608X85
C23, C24: 100UF10X10.5; 10_X_10.5
C25: 1000UF; 16_X_25
C26, C27: 0.1 uF; CAPC1608X85
C28, C29: 100 uF; CAPMP7343X310N
C33: 4.7uF; C0603
C34: 10.0nF; C0603
C35: 220uF; D/7343-31R
C36: 22.0uF; C1210
C37: 0.1uF; C0603
CON5: XT30UPB-F
D43: zm4728; DIOMELF5024
D44: 1n5401; DO-201AD
D45: ss510; DIOM5226X290N
D46: 3A/40V/500mV; SMA-DIODE
L2: SWPA8040/10uH; SWPA8040
L3: 56uh; WE-PD_7345R
Q27: IRLB3036PbF; TO220BV
R36: 20; RESAD724W46L381D178B
R37: 1k; RESC1608X60
R38: 10k; RESC1608X60
R39: 2.94k; RESC1608X60
R40: 1.5k; RESC1608X60
R41: 57k; RESC1608X60
R42: 10k; PV36X
R43: 10k; R0603
R44: 5.9k; R0603
U9: SN74AHCT1G08; SOT23-5
U10: AMS1117-5.0; SOT223
U11: TPS5430; POWERPAD-SOIC-8
U$5: LM2587; TO263-5

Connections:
12V: C23.1, C33.1, C36.1, L3.1, U11.7 (VIN), U$5.5; also elsewhere on the board
+3.3V: C35.+, C37.1, L2.P2 (2), R43.2; also elsewhere on the board
+5V: C27.1, C29.1 (+), U9.1, U9.5, U10.2, U10.4; also elsewhere on the board
+12V: C26.1, C28.1 (+), U10.3
GND: C21.2, C22.2, C23.2, C24.2, C25.2, C26.2, C27.2, C28.2 (-), C29.2 (-), C33.2, C35.-, C36.2, C37.2, D46.A, Q27.S, R38.1, R40.1, R44.1, U9.3, U10.1, U11.6 (GND), U11.9 (GND), U11.P$1 (GND), U11.P$2 (GND), U11.P$3 (GND), U11.P$4 (GND), U11.P$5 (GND), U11.P$6 (GND), U$5.3, U$5.6, U$5.P$1, U$5.P$2; also elsewhere on the board
KICKER: U9.2; also elsewhere on the board
KICKER_5V: R37.1, U9.4
unnamed: C34.2, D46.C, L2.P1 (1), U11.8 (PH)
unnamed: CON5.+, D44.A, Q27.D, R36.2
unnamed: C21.1, R36.1
unnamed: D43.1 (C), D44.C
unnamed: Q27.G, R37.2, R38.2
unnamed: D45.1 (A), L3.2, U$5.4
unnamed: R39.2, U$5.1
unnamed: C22.1, R39.1
unnamed: R41.1, R42.3
unnamed: R40.2, R42.1, R42.2, U$5.2
unnamed: R43.1, R44.2, U11.4 (VSNS)
unnamed: C34.1, U11.1 (BOOT)
VCC: C24.1, C25.1, CON5.-, D43.2 (A), D45.2 (C), R41.2; also elsewhere on the board

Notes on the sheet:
sn74ahct1g08
simple way to use 3.3v logic control a 5v fet
ams1117-5.0v


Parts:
C31, C32: 0.1 uF; CAPC1608X85
CON6, CON7: XT60PB-M
J4: 686112183822
JP2, JP3, JP4, JP5: PINHD-1X1; 1X01

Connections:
12V: C31.1, CON7.+, JP4.1; also elsewhere on the board
+3.3V: JP2.1; also elsewhere on the board
+5V: JP3.1; also elsewhere on the board
GND: C31.2, C32.2, CON6.-, CON7.-; also elsewhere on the board
INA1: J4.4; also elsewhere on the board
INA2: J4.8; also elsewhere on the board
INA3: J4.2; also elsewhere on the board
INA4: J4.7; also elsewhere on the board
KICKER: J4.5; also elsewhere on the board
LG: J4.6; also elsewhere on the board
MOTOR_12V: C32.1, CON6.+; also elsewhere on the board
PWM1: J4.3; also elsewhere on the board
PWM2: J4.10; also elsewhere on the board
PWM3: J4.1; also elsewhere on the board
PWM4: J4.9; also elsewhere on the board
RX2: J4.12; also elsewhere on the board
TX2: J4.11; also elsewhere on the board
VCC: JP5.1; also elsewhere on the board

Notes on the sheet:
motor power
everything else



Board: 2 copper layers, 176.0 x 171.3 mm, 190 parts (90 on the bottom side), 125 nets.

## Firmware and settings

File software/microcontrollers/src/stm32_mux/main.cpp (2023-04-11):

#include <Arduino.h>
#include <PacketSerial.h>
#include <array>

#include "angle.h"
#include "shared_config.h"
#include "stm32_mux/include/config.h"

// State
struct LineData line;
std::array<uint16_t, LDR_COUNT> activatedCount;

// Serial
PacketSerial teensySerial;

// Sets an LDR MUX to select a specific channel.
void selectLDRMUXChannel(LDRMUX mux, uint8_t channel) {
    switch (mux) {
    case MUX1:
        digitalWrite(PIN_LDRMUX1_S0, channel & 1);
        digitalWrite(PIN_LDRMUX1_S1, (channel >> 1) & 1);
        digitalWrite(PIN_LDRMUX1_S2, (channel >> 2) & 1);
        digitalWrite(PIN_LDRMUX1_S3, (channel >> 3) & 1);
    case MUX2:
        digitalWrite(PIN_LDRMUX2_S0, channel & 1);
        digitalWrite(PIN_LDRMUX2_S1, (channel >> 1) & 1);
        digitalWrite(PIN_LDRMUX2_S2, (channel >> 2) & 1);
        digitalWrite(PIN_LDRMUX2_S3, (channel >> 3) & 1);
    }
}

// Reads the value of an LDR 0-indexed counting clockwise from 000º.
uint16_t readLDR(uint8_t index) {
    const auto real_index = LDR_MAP_REVERSE[index];
    selectLDRMUXChannel(real_index < 16 ? MUX1 : MUX2, real_index % 16);
    return analogRead(real_index < 16 ? PIN_LDRMUX1_SIG : PIN_LDRMUX2_SIG);
}

// Finds the position of the line.
void findLine() {
    // Read LDRs, the LDRs need to be activated for a while to reduce noise
    for (uint8_t i = 0; i < LDR_COUNT; ++i) {
        if (readLDR(i) > LDR_THRESHOLDS[i]) {
            if (activatedCount[i] != UINT16_MAX) ++activatedCount[i];
        } else
            activatedCount[i] = 0;
    }

    // Get the matches (to the line)
    uint8_t matchCount = 0;
    uint8_t matches[LDR_COUNT];
    for (uint8_t i = 0; i < LDR_COUNT; ++i) {
        if (activatedCount[i] >= LDR_ACTIVATION_THRESHOLD) {
            matches[matchCount] = i;
            ++matchCount;
        }
    }

    // No match (to the line) was found
    if (matchCount == 0) {
        line.angleBisector = NO_LINE_INT16;
        line.size = NO_LINE_UINT8;
        return;
    }

    // Find the cluster
    float maxAngleDifference = 0;
    uint8_t clusterStart = LDR_COUNT, clusterEnd = LDR_COUNT;
    // Iterate through all combinations of matching indices and find
    // the pair with the greatest minimum difference
    for (uint8_t i = 0; i < matchCount - 1; ++i) {
        for (uint8_t j = i + 1; j < matchCount; ++j) {
            auto angleDifference =
                fabsf(LDR_BEARINGS[matches[i]] - LDR_BEARINGS[matches[j]]);
            angleDifference =
                angleDifference > 180 ? 360 - angleDifference : angleDifference;
            if (angleDifference > maxAngleDifference) {
                maxAngleDifference = angleDifference;
                clusterStart = matches[i];
                clusterEnd = matches[j];
            }
        }
    }

    // No cluster was found
    if (clusterStart == LDR_COUNT) {
        line.angleBisector = NO_LINE_INT16;
        line.size = NO_LINE_UINT8;
        return;
    }

    // Calculate the line angle and size
    const auto clusterStartAngle = LDR_BEARINGS[clusterStart];
    const auto clusterEndAngle = LDR_BEARINGS[clusterEnd];
    const auto clusterMidpoint =
        bearingMidpoint(clusterStartAngle, clusterEndAngle);

    // Sets lineAngle as perpendicular to angle of the midpoint of cluster ends
    line.angleBisector = roundf(bearingToAngle(clusterMidpoint) * 100);
    // Sets lineSize as the ratio of the cluster size to 180°
    line.size = roundf(
        (smallerBearingDiff(clusterStartAngle, clusterEndAngle) / 180.0F) *
        100);
}

// CALIBRATE: Determines threshold values for the photodiodes.
void printLDRThresholds() {
    // min = green (field), max = white (line)
    uint16_t min[LDR_COUNT], max[LDR_COUNT];
    for (int i = 0; i < LDR_COUNT; ++i) {
        min[i] = 0xFFFF;
        max[i] = 0x0000;
    }

    const auto endTime = millis() + LDR_CALIBRATION_DURATION;
    while (millis() < endTime) {
        for (uint8_t i = 0; i < LDR_COUNT; ++i) {
            const auto value = readLDR(i);
            if (value < min[i]) min[i] = value;
            if (value > max[i]) max[i] = value;
        }
    }

    // Print the thresholds (averages of min and max)
    TEENSY_SERIAL.printf("Thresholds: {");
    for (uint8_t i = 0; i < LDR_COUNT; ++i) {
        const auto threshold =
            (max[i] - min[i]) * LDR_CALIBRATION_MULTIPLIER + min[i];
        TEENSY_SERIAL.printf("%d, ", (uint16_t)threshold);
    }
    TEENSY_SERIAL.printf("}\n");
}

// DEBUG: Prints detected line data.
void printLDR() {
    findLine();

    uint16_t values[LDR_COUNT];
    for (uint8_t i = 0; i < LDR_COUNT; ++i) values[i] = readLDR(i);

    if (line.exists()) {
        TEENSY_SERIAL.printf("%4d.%02dº %01d.%02d |", line.angleBisector / 100,
                             abs(line.angleBisector % 100), line.size / 100,
                             line.size % 100);
    } else {
        TEENSY_SERIAL.printf("              |");
    }
    for (uint8_t i = 0; i < LDR_COUNT / 2; ++i)
        TEENSY_SERIAL.printf("%s", values[i] > LDR_THRESHOLDS[i] ? "1" : " ");
    TEENSY_SERIAL.printf("|");
    for (uint8_t i = LDR_COUNT / 2; i < LDR_COUNT; ++i)
        TEENSY_SERIAL.printf("%s", values[i] > LDR_THRESHOLDS[i] ? "1" : " ");
    TEENSY_SERIAL.printf("| ");
    for (uint8_t i = 0; i < LDR_COUNT / 2; ++i)
        TEENSY_SERIAL.printf("%4d ", values[i]);
    TEENSY_SERIAL.printf("| ");
    for (uint8_t i = LDR_COUNT / 2; i < LDR_COUNT; ++i)
        TEENSY_SERIAL.printf("%4d ", values[i]);
    TEENSY_SERIAL.printf("\n");
}

// ------------------------------ MAIN CODE START ------------------------------
void onTeensyPacket(const byte *buf, size_t size) {
    MUXRXPayload payload;
    // Don't continue if the payload is invalid
    if (size != sizeof(payload)) return;
    memcpy(&payload, buf, sizeof(payload));

    // If the STM32 is in calibration mode, print the thresholds
    if (payload.calibrating) { // defaults to false
        TEENSY_SERIAL.println("Calibrating...");
        while (1) printLDRThresholds();
    }
}

void setup() {
    // Turn on the debug LED
    pinMode(PIN_LED_DEBUG, OUTPUT);
    digitalWrite(PIN_LED_DEBUG, HIGH);

    // Initialise pins
    pinMode(PIN_LDRMUX1_S0, OUTPUT);
    pinMode(PIN_LDRMUX1_S1, OUTPUT);
    pinMode(PIN_LDRMUX1_S2, OUTPUT);
    pinMode(PIN_LDRMUX1_S3, OUTPUT);
    pinMode(PIN_LDRMUX2_S0, OUTPUT);
    pinMode(PIN_LDRMUX2_S1, OUTPUT);
    pinMode(PIN_LDRMUX2_S2, OUTPUT);
    pinMode(PIN_LDRMUX2_S3, OUTPUT);
    pinMode(PIN_LDRMUX1_SIG, INPUT);
    pinMode(PIN_LDRMUX2_SIG, INPUT);

    analogReadResolution(12);

    // Initialise serial
    TEENSY_SERIAL.begin(TEENSY_MUX_BAUD_RATE);
#ifdef DEBUG
    DEBUG_SERIAL.begin(DEBUG_BAUD_RATE);
    while (!DEBUG_SERIAL) delay(10);
#endif
    teensySerial.setStream(&TEENSY_SERIAL);
    teensySerial.setPacketHandler(&onTeensyPacket);

    // Line data is always new
    line.newData = true;

    // Turn off the debug LED
    digitalWrite(PIN_LED_DEBUG, LOW);
}

void loop() {
    // Read packets from serial
    teensySerial.update();

    // Find the line
    findLine();

    // Send the line data over serial to Teensy
    byte buf[sizeof(MUXTXPayload)];
    memcpy(buf, &line, sizeof(line));
    teensySerial.send(buf, sizeof(buf));

    // ------------------------------ START DEBUG ------------------------------
    // // Print LDR data
    // printLDR();

    // // Print loop time
    // printLoopTime();
    // ------------------------------- END DEBUG -------------------------------
}
// ------------------------------- MAIN CODE END -------------------------------

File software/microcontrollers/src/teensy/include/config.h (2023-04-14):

#ifndef TEENSY_CONFIG_H
#define TEENSY_CONFIG_H

#include <HardwareSerial.h>
#include <array>

#include "shared_config.h"
#include "vector.h"

// Flags
#define MASTER
// #define DEBUG
#define DEBUG_TEENSY
// #define DEBUG_MUX
// #define DEBUG_IMU
// #define DEBUG_TOF
// #define DEBUG_CORAL
// #define CALIBRATE_IMU
// #define CALIBRATE_MUX
// #define CALIBRATE_ROBOT_ANGLE
// #define CALIBRATE_BALL_CURVE
// #define CALIBRATE_AVOIDANCE
// #define CALIBRATE_LINE_TRACK
// #define CALIBRATE_GOAL_MOVEMENT
// #define DISABLE_DRIBBLER

// Macro Flags
#ifdef DEBUG_TEENSY
    #define DEBUG
#endif
#ifdef DEBUG_MUX
    #define DEBUG
#endif
#ifdef DEBUG_IMU
    #define DEBUG
#endif
#ifdef DEBUG_TOF
    #define DEBUG
#endif
#ifdef DEBUG_CORAL
    #define DEBUG
#endif
#ifdef CALIBRATE_IMU
    #define CALIBRATE
    #define DONT_WAIT_FOR_SUBPROCESSOR_INIT
#endif
#ifdef CALIBRATE_MUX
    #define CALIBRATE
    #define DONT_WAIT_FOR_SUBPROCESSOR_INIT
#endif
#ifdef CALIBRATE_ROBOT_ANGLE
    #define CALIBRATE
#endif
#ifdef CALIBRATE_BALL_CURVE
    #define CALIBRATE
#endif
#ifdef CALIBRATE_AVOIDANCE
    #define CALIBRATE
#endif
#ifdef CALIBRATE_LINE_TRACK
    #define CALIBRATE
#endif
#ifdef CALIBRATE_GOAL_MOVEMENT
    #define CALIBRATE
#endif

// Pins
#define PIN_LED_DEBUG 13

#define PIN_RX_CORAL 1 // Serial1
#define PIN_TX_CORAL 0
#define CORAL_SERIAL Serial1

#define PIN_RX_STM32_MUX 8 // Serial2
#define PIN_TX_STM32_MUX 7
#define MUX_SERIAL       Serial2

#define PIN_RX_STM32_TOF 14 // Serial3
#define PIN_TX_STM32_TOF 15
#define TOF_SERIAL       Serial3

#define PIN_RX_STM32_IMU 17 // Serial4
#define PIN_TX_STM32_IMU 16
#define IMU_SERIAL       Serial4

#define PIN_MOTOR_FL_PWM 2
#define PIN_MOTOR_FR_PWM 3
#define PIN_MOTOR_BL_PWM 4
#define PIN_MOTOR_BR_PWM 5
#define PIN_MOTOR_FL_DIR 9
#define PIN_MOTOR_FR_DIR 10
#define PIN_MOTOR_BL_DIR 11
#define PIN_MOTOR_BR_DIR 12
// Bot 1
#define MOTOR_FL_REVERSED false
#define MOTOR_FR_REVERSED false
#define MOTOR_BL_REVERSED false
#define MOTOR_BR_REVERSED false
// // Bot 2
// #define MOTOR_FL_REVERSED true
// #define MOTOR_FR_REVERSED true
// #define MOTOR_BL_REVERSED true
// #define MOTOR_BR_REVERSED false

#define PIN_DRIBBLER_PWM 18
#define PIN_LIGHTGATE    22
#define PIN_KICKER       23

// Sensor Config
// To have switched sides of the line, the line angle must have jumped this much
#define LINE_ANGLE_SWITCH_ANGLE 90.0F
// for this number of times
#define LINE_ANGLE_SWITCH_COUNT 2
// when compared to this number of previous line angles
#define LINE_ANGLE_HISTORY 2

#define LIGHTGATE_THRESHOLD 800

#define TOF_MAX_DISTANCE 70.0F // in cm (at home)
// #define TOF_MAX_DISTANCE 130.0F // in cm (at computer lab)

// true if blue is the offensive goal, false if yellow is the offensive goal
#define TARGET_BLUE_GOAL false

// Movement Config
#define DRIVE_STALL_SPEED          (int16_t)20
#define DRIVE_MAX_SPEED            (int16_t)1023
#define DRIBBLER_ARM_SPEED         (int16_t)128
#define DRIBBLER_SPEED             (int16_t)200 // stalls at 177
#define DRIBBLER_ARM_DURATION      3000         // in ms
#define KICKER_ACTIVATION_DURATION 100          // in ms
#define KICKER_COOLDOWN_DURATION   3000         // in ms

// ------------------------------- Robot Heading -------------------------------

#define KU_ROBOT_ANGLE 8.0e1F // tuned to ±0.5e1F
// ZN (no overshoot)  : kP=0.2  kI=0.4  kD=0.066
// ZN (some overshoot): kP=0.33 kI=0.66 kD=0.11
// ZN (classic)       : kP=0.6  kI=1.2  kD=0.075
#define KP_ROBOT_ANGLE                  0.3 * KU_ROBOT_ANGLE
#define KI_ROBOT_ANGLE                  0.6
#define KD_ROBOT_ANGLE                  30 // 25 for 300, 40 for 600
#define MAXI_ROBOT_ANGLE                1.0e4F
#define MAX_SETPOINT_CHANGE_ROBOT_ANGLE 0.1F
#define MIN_DT_ROBOT_ANGLE              5000 // in µs, minimum value for kD to have effect
#define STATIONARY_SCALER_ROBOT_ANGLE   2.0F
// Old PID version
// #define KP_ROBOT_ANGLE 3.6e1F  // tuned to ±0.2e1F
// #define KI_ROBOT_ANGLE 2.5e-5F // tuned to ±0.5e-5F
// #define KD_ROBOT_ANGLE 5.0e6F  // tuned to ±0.5e6F
// Old PD version but the kP was probably too high
// #define KP_ROBOT_ANGLE 5.8e1F // tuned to ±0.1e1F
// #define KI_ROBOT_ANGLE 0
// #define KD_ROBOT_ANGLE 2.7e6F // tuned to ±0.05e6F

// -------------------------------- Robot Speed --------------------------------

// This is the main speed the robot will be travelling at throughout gameplay,
// and one of the fastest speeds. Other aspects of gameplay will start from this
// speed and decelerate where necessary.
#define BASE_SPEED 600.0F

// ------------------------------- Ball Movement -------------------------------

// Multiplier = e^(DECAY * (START - Ball Distance))
// https://www.desmos.com/calculator/ixwhywbd5i
// This is the distance where we start curving maximally as the ball gets closer
#define BALL_MOVEMENT_MAX_CURVE 13.0F // in cm, tuned to ±1.0
// The larger the value, the faster the decay of the angle offset
#define BALL_MOVEMENT_DECAY 0.03F
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

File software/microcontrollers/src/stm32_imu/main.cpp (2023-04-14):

#include <Adafruit_BNO055.h>
#include <Arduino.h>
#include <EEPROM.h>
#include <PacketSerial.h>
#include <Wire.h>
#include <array>

#include "angle.h"
#include "shared_config.h"
#include "stm32_imu/include/config.h"
#include "util.h"

// State
IMUData imuData;

// Serial managers
PacketSerial teensySerial;

// IMU (Sensor ID, I2C Address, I2C Wire)
Adafruit_BNO055 bno = Adafruit_BNO055(55, I2C_ADDRESS_BNO055, &Wire);

// Reads the current robot angle from the IMU.
float readRobotAngle() {
    sensors_event_t eulerAngles;
    bno.getEvent(&eulerAngles, Adafruit_BNO055::VECTOR_EULER);
    return bearingToAngle(eulerAngles.orientation.x);
}

// DEBUG: Prints all data read from IMU sensors.
void printAllIMUData() {
    // Get sensor data
    sensors_event_t eul, gyr, lac, mag, acc, gra;
    bno.getEvent(&eul, Adafruit_BNO055::VECTOR_EULER);
    bno.getEvent(&gyr, Adafruit_BNO055::VECTOR_GYROSCOPE);
    bno.getEvent(&acc, Adafruit_BNO055::VECTOR_ACCELEROMETER);
    bno.getEvent(&lac, Adafruit_BNO055::VECTOR_LINEARACCEL);
    bno.getEvent(&gra, Adafruit_BNO055::VECTOR_GRAVITY);
    bno.getEvent(&mag, Adafruit_BNO055::VECTOR_MAGNETOMETER);

    // Get calibration states
    uint8_t systemCalib, gyroCalib, accCalib, magCalib;
    bno.getCalibration(&systemCalib, &gyroCalib, &accCalib, &magCalib);

    // Print everything to serial
    const auto printVector = [](const char *name, const sensors_vec_t &vector) {
        TEENSY_SERIAL.printf(
            "%s: x = %4d.%02d y = %4d.%02d z = %4d.%02d\n", name,
            (int16_t)vector.x, abs((int32_t)(vector.x * 100) % 100),
            (int16_t)vector.y, abs((int32_t)(vector.y * 100) % 100),
            (int16_t)vector.z, abs((int32_t)(vector.z * 100) % 100));
    };
    printVector("Euler Angle (º)            ", eul.orientation);
    printVector("Angular Velocity (rad s⁻¹) ", gyr.gyro);
    printVector("Acceleration (m s⁻²)       ", acc.acceleration);
    printVector("Linear Acceleration (m s⁻²)", lac.acceleration);
    printVector("Gravity (m s⁻²)            ", gra.acceleration);
    printVector("Magnetic Field (μT)        ", mag.magnetic);

    TEENSY_SERIAL.printf(
        "Calibration: System = %d Gyroscope = %d Accelerometer = %d "
        "Magnetometer = %d\n\n",
        systemCalib, gyroCalib, accCalib, magCalib);
}

// CALIBRATE: Calibrates the IMU and stores the offsets in EEPROM.
void calibrate() {
    TEENSY_SERIAL.printf("Calibrating...\n");
    delay(1000);

    // Calibration phase
    while (!bno.isFullyCalibrated()) {
        printAllIMUData();
        delay(1000);
    }
    printAllIMUData();

    // Calibration completed
    adafruit_bno055_offsets_t offsets;
    bno.getSensorOffsets(offsets);

    // Print results
    const auto printVector = [](const char *name, const float x, const float y,
                                const float z) {
        TEENSY_SERIAL.printf("%s: x = %11d y = %11d z = %11d\n", name, x, y, z);
    };
    TEENSY_SERIAL.printf("\nCalibration Complete\n");
    TEENSY_SERIAL.printf("\nOffsets\n");
    printVector("Accelerometer: ", offsets.accel_offset_x,
                offsets.accel_offset_y, offsets.accel_offset_z);
    printVector("Gyroscope    : ", offsets.gyro_offset_x, offsets.gyro_offset_y,
                offsets.gyro_offset_z);
    printVector("Magnetometer : ", offsets.mag_offset_x, offsets.mag_offset_y,
                offsets.mag_offset_z);
    TEENSY_SERIAL.printf("Accelerometer Radius: %d\n", offsets.accel_radius);
    TEENSY_SERIAL.printf("Magnetometer Radius : %d\n", offsets.mag_radius);

    TEENSY_SERIAL.printf("\n\nStoring calibration data to EEPROM...\n");
    EEPROM.put(EEPROM_ADDRESS_HAS_OFFSETS, true);
    EEPROM.put(EEPROM_ADDRESS_OFFSETS, offsets);
    TEENSY_SERIAL.printf("Offsets Saved\n");
}

// ------------------------------ MAIN CODE START ------------------------------
void onTeensyPacket(const byte *buf, size_t size) {
    MUXRXPayload payload;
    // Don't continue if the payload is invalid
    if (size != sizeof(payload)) return;
    memcpy(&payload, buf, sizeof(payload));

    // If the STM32 is in calibration mode, run the BNO055 calibration routine
    if (payload.calibrating) { // defaults to false
        calibrate();
        while (1) {};
    }
}

void setup() {
    // Turn on the debug LED
    pinMode(PIN_LED_DEBUG, OUTPUT);
    digitalWrite(PIN_LED_DEBUG, HIGH);

    // Initialise pins
    Wire.setSDA(PIN_SDA_IMU);
    Wire.setSCL(PIN_SCL_IMU);

    // Initialise serial
    TEENSY_SERIAL.begin(TEENSY_IMU_BAUD_RATE);
#ifdef DEBUG
    DEBUG_SERIAL.begin(DEBUG_BAUD_RATE);
    while (!DEBUG_SERIAL) delay(10);
#endif
    teensySerial.setStream(&TEENSY_SERIAL);
    teensySerial.setPacketHandler(&onTeensyPacket);

    // Initialise I2C
    Wire.begin();
    Wire.setClock(400000); // Use 400 kHz I2C

    // Initialise IMU
    if (!bno.begin()) {
#ifdef DEBUG
        DEBUG_SERIAL.println("IMU not found");
#endif
        // Blink the debug LED if IMU not found
        while (1) {
            digitalWrite(PIN_LED_DEBUG, HIGH);
            delay(100);
            digitalWrite(PIN_LED_DEBUG, LOW);
            delay(100);
        }
    }
    bno.setExtCrystalUse(false); // we do not have an external crystal
    bno.setMode(OPERATION_MODE_IMUPLUS);

    // Attempt to load IMU offsets
    bool hasOffsets;
    EEPROM.get(EEPROM_ADDRESS_HAS_OFFSETS, hasOffsets);
    if (hasOffsets) {
        adafruit_bno055_offsets_t offsets;
        EEPROM.get(EEPROM_ADDRESS_OFFSETS, offsets);
        bno.setSensorOffsets(offsets);

        // Turn off the debug LED
        digitalWrite(PIN_LED_DEBUG, LOW);
    }
}

void loop() {
    // Read IMU data
    imuData.newData = true;
    imuData.robotAngle = roundf(readRobotAngle() * 100); // probably blocking

    // Send the IMU data over serial to Teensy
    byte buf[sizeof(IMUTXPayload)];
    memcpy(buf, &imuData, sizeof(imuData));
    teensySerial.send(buf, sizeof(buf));
    imuData.newData = false;

    // ------------------------------ START DEBUG ------------------------------

    // calibrate();
    // while (1) {}

    // // Scan for I2C devices
    // scanI2C(TEENSY_SERIAL, Wire);
    // delay(5000);

    // // Print all IMU data
    // printAllIMUData();
    // delay(1000);

    // // Print payload
    // TEENSY_SERIAL.printf("bearing: %3d.%02dº\n", bearing / 100, bearing %
    // 100);

    // // Print loop time
    // printLoopTime(2000);

    // ------------------------------- END DEBUG -------------------------------
}
// ------------------------------- MAIN CODE END -------------------------------

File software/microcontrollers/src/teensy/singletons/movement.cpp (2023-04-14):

#include "movement.h"

#include <Arduino.h>
#include <cstdint>

#include "angle.h"
#include "teensy/include/config.h"
#include "vector.h"

Movement::Movement() {}

void Movement::init() {
    // Values from https://www.pjrc.com/teensy/td_pulse.html
    // (based on F_CPU_ACTUAL = 600 MHz)
    analogWriteResolution(10);

    // Iniialise motor pins
    pinMode(PIN_MOTOR_FL_DIR, OUTPUT);
    pinMode(PIN_MOTOR_FR_DIR, OUTPUT);
    pinMode(PIN_MOTOR_BL_DIR, OUTPUT);
    pinMode(PIN_MOTOR_BR_DIR, OUTPUT);
    analogWriteFrequency(PIN_MOTOR_FL_PWM, 146484);
    analogWriteFrequency(PIN_MOTOR_FR_PWM, 146484);
    analogWriteFrequency(PIN_MOTOR_BL_PWM, 146484);
    analogWriteFrequency(PIN_MOTOR_BR_PWM, 146484);
    pinMode(PIN_MOTOR_FL_PWM, OUTPUT);
    pinMode(PIN_MOTOR_FR_PWM, OUTPUT);
    pinMode(PIN_MOTOR_BL_PWM, OUTPUT);
    pinMode(PIN_MOTOR_BR_PWM, OUTPUT);

    // Initialise kicker pin
    pinMode(PIN_KICKER, OUTPUT);

#ifndef DISABLE_DRIBBLER
    // Initialise dribbler pins
    analogWriteFrequency(PIN_DRIBBLER_PWM, 1000);
    pinMode(PIN_DRIBBLER_PWM, OUTPUT);

    // Arm dribbler
    analogWrite(PIN_DRIBBLER_PWM, DRIBBLER_ARM_SPEED);
    delay(DRIBBLER_ARM_DURATION);
#endif
}

void Movement::updateHeadingController(const float angle) {
    _actualHeading = angle;
}

void Movement::setStop(bool maintainHeading) {
    if (maintainHeading) {
        // Since we want to maintain heading, let's just set velocity to 0
        velocity = 0;
    } else {
        // Since we don't need to maintain heading, we can brake the drivers
        _brake = true;
    }
}

// Sets the robot to move to a certain cartesian position on the field given the
// position of the two goals. We are also able to move to a target heading.
void Movement::setMoveTo(const Vector &robot, const Point &destination,
                         const float targetHeading) {
    const auto relativeDestination = -robot + Vector::fromPoint(destination);

    // Update move to state
    if (_lastDestination == nullptr || *_lastDestination != destination) {
        // A new move to routine just started
        delete _lastDestination;
        _lastDestination = new Point(destination);
        _initialDistance = relativeDestination.distance;
        moveToController.reset();
    }

    // Pack it into instructions for our update function
    _moveToActive = true;
    angle = relativeDestination.angle;
    if (relativeDestination.distance > MOVE_TO_PRECISION) {
        // The destination hasn't been reached
        // We square the error to make it decelerate linearly
        const auto controllerError = -powf(relativeDestination.distance, 2);
        velocity = moveToController.advance(controllerError);
        heading = (targetHeading - _actualHeading) *
                  fmin(relativeDestination.distance / _initialDistance, 1.0);
    } else {
        // The destination has basically been reached
        velocity = 0;
        heading = targetHeading;
    }
}

void Movement::setLineTrack(const float lineDepth, const float targetLineAngle,
                            const float targetLineDepth,
                            const bool trackRightSide) {
    // Update line track state
    if (_lastTargetLineAngle == NAN ||
        _lastTargetLineAngle != targetLineAngle) {
        // A new line track routine just started
        _lastTargetLineAngle = targetLineAngle;
        lineTrackController.reset();
    }

    // Compute error to use in control loop
    const auto trackingForwards =
        targetLineAngle >= -90 && targetLineAngle <= 90;
    const auto controllerError = trackingForwards ^ trackRightSide
                                     ? lineDepth - targetLineDepth
                                     : targetLineDepth - lineDepth;

    // Pack it into instructions for our update function
    _lineTrackActive = true;
    // Scale the controller output linearly to velocity with a reference
    // velocity of 300 (we tune it at that)
    angle = targetLineAngle - _actualHeading +
            lineTrackController.advance(controllerError, (float)velocity / 300,
                                        true);
}

void Movement::setMoveOnLineToBall(const float lineDepth, const Vector &ball,
                                   const float targetLineDepth,
                                   const bool trackRightSide) {
    // Update move on line to ball state
    if (_lastTrackBallRightSide == nullptr ||
        *_lastTrackBallRightSide != trackRightSide) {
        // A new move on line to ball routine just started
        delete _lastTrackBallRightSide;
        _lastTrackBallRightSide = new bool(trackRightSide);
        moveOnLineToBallController.reset();
    }

    // Take a robot approaching the left boundary line as reference:
    // 1. If the ball is to the left/behind the robot, line track
    // backwards. Note that even if the ball is to the right of the
    // robot, we choose to line track if it's too far back, as the
    // robot's attempt to curve behind the ball would likely lie
    // beyond the line.
    // 2. If the ball is to the left/in front of the robot, line track
    // forwards.
    if (trackRightSide
            ? (ball.angle <= 0 || ball.angle > LINE_TRACKING_NO_CURVE_THRESHOLD)
            : (ball.angle >= 0 ||
               ball.angle < -LINE_TRACKING_NO_CURVE_THRESHOLD)) {
        // We should be line tracking here

        const auto adjustedBallAngle = clipAngle(ball.angle - _actualHeading);
        const auto ballDistance =
            (trackRightSide
                 ? (adjustedBallAngle > -90 && adjustedBallAngle <= 0)
                 : (adjustedBallAngle < 90 && adjustedBallAngle >= 0))
                ? ball.distance
                : -ball.distance;
        const auto correction =
            moveOnLineToBallController.advance(ballDistance);
        velocity = abs(correction);
        setLineTrack(lineDepth, correction < 0 ? 0 : 180, targetLineDepth,
                     trackRightSide);
    } else {
        // Since the ball is within a range where we can feasible curve
        // to it, let's just do that.

        // Don't override ball curve values, so don't do anything
    }

    _moveOnLineToBallActive = true;
}

// Sets the velocity to decrease such that deceleration is linear from the start
// speed to the end speed, using a multiplier between 0.0 and 1.0.
void Movement::setLinearDecelerate(const int16_t startSpeed,
                                   const int16_t endSpeed,
                                   const float multiplier,
                                   const bool replaceVelocity) {
    const auto newVelocity =
        (startSpeed - endSpeed) * powf(fmin(multiplier, 1.0), 2) + endSpeed;
    velocity = replaceVelocity ? newVelocity : fmin(velocity, newVelocity);
}
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

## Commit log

2023-03-01 Create folder for PCB schematics
2023-03-01 Update PCB directory structure
2023-03-17 Refactor code, fix bug in movement, and code IMU
    [config.h, main.cpp, util.cpp]
2023-03-18 Add bluetooth code and clean up STM32 serial
2023-03-18 Refactor teensy code and drive motors when calibrating IMU
2023-03-18 Refactor code to use angle instead of bearing
2023-04-01 Move Teensy code into Sensors and Movement classes
2023-04-04 Add camera code
2023-04-04 Update CameraData payload on Teensy side
2023-04-07 Print goal location in debug output
2023-04-08 Tune ball kalman filter (a little)
2023-04-08 Update camera parameters
2023-04-08 Implement kalman filter for goals
2023-04-08 Fix some bugs and got localisation working
    [config.h, main.cpp, movement.cpp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]
2023-04-09 Fix a few bugs here and there, basically finish calibrating ball curve and robot heading, and implement wall avoidance
    [config.h, main.cpp, movement.cpp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]
2023-04-11 Add multiplier to light sensor threshold calibration
2023-04-11 Refactor teensy code organisation
2023-04-12 Improve calibration
2023-04-13 Calibrate camera for bot 2
2023-04-13 Update bot 1 camera calibration
2023-04-14 Add science centre calibrations
2024-01-07 added l1 elec files
    [l1 pcb v42.brd, l1_pcb_v38.sch]
2024-01-07 added l2 elec files
    [l2 pcb v15.brd, l2_pcb_v4.sch]
2024-01-07 added l3 elec files
    [pcb l3 v28.brd, pcb_l3_v17.sch]
2024-01-07 added l4 elec files
    [pcb l4 v18.sch, pcb l4 v26.brd]
2024-01-07 Rename l1 pcb v38.pdf to l1.pdf
2024-01-07 Rename l1 pcb v42.brd to l1.brd
    [l1.brd]

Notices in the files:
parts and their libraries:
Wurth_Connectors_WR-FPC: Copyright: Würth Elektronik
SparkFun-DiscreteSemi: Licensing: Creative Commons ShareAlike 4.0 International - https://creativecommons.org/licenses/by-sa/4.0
